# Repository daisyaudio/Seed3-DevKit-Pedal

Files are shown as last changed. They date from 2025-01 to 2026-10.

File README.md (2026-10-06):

# Seed3 Pedal Dev Kit

Seed3 Pedal Dev Kit

## An Effects Pedal Platform for the Daisy Seed3

The Seed3 Pedal Dev Kit provides everything you need to design and prototype your next Daisy-based effects pedal on a single, purpose-built board. Create powerful DSP effects — massive reverbs, delay networks, complex loopers, spectral processors, and granular engines the likes of which have yet to grace the pedal world.

With industry-standard components and circuitry onboard, moving a Daisy design into production has never been easier. On top of stereo I/O and a host of electromechanical controls, the Dev Kit includes DIN MIDI I/O, a TRS expression input, a microSD socket, and a USB-C port. Take your DSP pedals to the next level with Daisy.

---

## Contents

- [Features](#features)
- [Specifications](#specifications)
- [Getting Started](#getting-started)
- [Making Your Own Project](#making-your-own-project)
- [Hardware Reference](#hardware-reference)
- [Resources & Support](#resources--support)
- [Open-Source Hardware](#open-source-hardware)
- [License](#license)

---

## Features

| Category | Details |
| --- | --- |
| **Audio** | Stereo audio input and output |
| **MIDI** | DIN MIDI In, Out, and Thru |
| **Expression** | TRS expression pedal input |
| **USB** | USB-C port connected to the Seed3's external USB peripheral, for USB features in your firmware |
| **Storage** | microSD slot for firmware updates, samples, presets, configuration, and more |
| **Potentiometers** | 6 × 10kΩ linear (B-taper) |
| **Footswitches** | 2 × footswitches |
| **Buttons** | 2 × tactile switches |
| **Toggle Switches** | 3 × toggle switches (1 × ON-OFF-ON, 2 × ON-ON) |
| **LEDs** | 1 × RGB LED, 1 × red LED |
| **Power** | 9V DC barrel jack, center negative (standard pedal supply) |

## Specifications

| Parameter | Value |
| --- | --- |
| Processor module | Daisy Seed3 |
| Supply voltage | 9V DC, center negative |
| Current draw | Firmware dependent |
| Reverse polarity protection | Yes |
| Audio codec / sample rate | TAC5242 / up to 32-bit, 192kHz |
| Input impedance | 1MΩ |
| Output impedance | 100Ω |
| Board dimensions | 197mm × 100mm |
| Expression input | TRS |
| MIDI connectors | 3 × 5-pin DIN (In, Out, Thru) |

> [!WARNING]
> Use a **center-negative** 9V DC supply.

## Getting Started

### 1. Install the toolchain

Follow the Daisy [C++ Getting Started guide](https://docs.daisy.audio/tutorials/cpp-dev-env/). It installs the toolchain and clones [DaisyExamples](https://github.com/daisyaudio/DaisyExamples), which includes [libDaisy](https://github.com/daisyaudio/libDaisy) (hardware library) and [DaisySP](https://github.com/daisyaudio/DaisySP) (DSP library).

### 2. Update libDaisy
 
The Pedal Dev Kit template and board support are newer than the copy of libDaisy included with DaisyExamples. From your `DaisyExamples` folder, update libDaisy to its latest version, fetch its own dependencies, and rebuild it:
 
```bash
git submodule update --remote libDaisy
git -C libDaisy submodule update --init --recursive
make -C libDaisy
```
 
The first line moves libDaisy to its latest version. The second fetches libDaisy's own dependencies, such as the STM32 drivers it needs to compile. The last line rebuilds libDaisy, which is required after any update.
 
> [!CAUTION]
> Running `git submodule update --init --recursive` or `git pull --recurse-submodules` from the `DaisyExamples` folder afterwards resets libDaisy to the older version DaisyExamples was built with. If that happens, run the three commands above again.

### 3. Build the template

The starting project for this kit is [`examples/devkits/Pedal-DevKit-Template`](https://github.com/daisyaudio/libDaisy/tree/master/examples/devkits/Pedal-DevKit-Template). From the `libDaisy` folder:

```bash
cd examples/devkits/Pedal-DevKit-Template
make
```

This creates `Pedal-DevKit-Template.bin` in the template's `build/` folder.

### 4. Flash the Seed3

> [!IMPORTANT]
> Program the Seed3 through the **USB-C port on the Seed3 module itself**, not the USB-C port on the Dev Kit board.

1. Connect a USB-C cable from your computer to the Seed3's USB-C port.
2. Hold **BOOT**, press and release **RESET**, then release **BOOT**.
3. From the template folder, run:

   ```bash
   make program-dfu
   ```

   Or, in the [Daisy Web Programmer](https://flash.daisy.audio/), upload the `Pedal-DevKit-Template.bin` file from the `build/` folder.

### 5. Power up and try it out

Connect a 9V center-negative supply to the barrel jack (J8) and plug in your instrument and amp. You can leave the Seed3's USB cable connected so you can watch the serial output.

> [!TIP]
> If you are experiencing USB noise from keeping the Seed3 connected to the computer, disconnect during testing.

The template:

- Passes audio from the inputs straight to the outputs.
- Blinks the red LED (LED1) and cycles the colors of the RGB LED (LED2).
- Echoes MIDI notes received on MIDI In to MIDI Out.
- Prints the state of every control over USB serial on the Seed3's USB-C port. Open any serial monitor to see it.

## Making Your Own Project

Edits only take effect on the pedal after you rebuild and reflash, so start your own project from a copy of the template.

1. Copy the `Pedal-DevKit-Template` folder into your `DaisyExamples` folder and rename it, for example `DaisyExamples/MyPedal`.
2. In the copied `Makefile`:
   - Set `TARGET` to your project name, for example `TARGET = MyPedal`.
   - Change `LIBDAISY_DIR` to point to libDaisy from the new location: `LIBDAISY_DIR = ../libDaisy`.
   - To use DaisySP, uncomment the DaisySP line and set `DAISYSP_DIR = ../DaisySP`.
3. Write your effect in `src/main.cpp`. Audio is processed in `AudioCallback()`: inputs are `in[0][i]` (left) and `in[1][i]` (right), and outputs are `out[0][i]` and `out[1][i]` (see [Audio](#audio)).
4. Rebuild and flash after every change:

   ```bash
   make
   make program-dfu
   ```

   Put the Seed3 into BOOT mode (step 4 above) before each `make program-dfu`.

> [!TIP]
> The template builds with debugging enabled (`DEBUG = 1`, `OPT = -Og`). For release builds, set `DEBUG = 0` and `OPT = -O3` in the Makefile. If your program grows too large for the Seed3's internal flash, see the [Daisy Bootloader guide](https://docs.daisy.audio/tutorials/_a7_Getting-Started-Daisy-Bootloader/).

## Hardware Reference

The **Ref** column lists each part's reference designator, as printed on the board's silkscreen.

### Pinout

Seed3 Pedal Dev Kit pinout

A printable [Pinout PDF](https://daisy.nyc3.cdn.digitaloceanspaces.com/products/seed-3-pedal/Seed3-Pedal-Dev-Kit-Pinout.pdf) is also available.

### Audio

| Jack | Ref | Silkscreen | Signal | Audio Callback |
| --- | --- | --- | --- | --- |
| Input Left | J2 | IN LEFT | `AUDIO_IN_L` | `in[0][i]` |
| Input Right | J4 | IN RIGHT | `AUDIO_IN_R` | `in[1][i]` |
| Output Left | J3 | OUT LEFT | `AUDIO_OUT_L` | `out[0][i]` |
| Output Right | J5 | OUT RIGHT | `AUDIO_OUT_R` | `out[1][i]` |

### Controls

| Control | Ref | Signal | Seed3 Pin | Notes |
| --- | --- | --- | --- | --- |
| Potentiometer 1 | VR1 | `POT_1` | D15 | 10kΩ B-taper |
| Potentiometer 2 | VR2 | `POT_2` | D16 | 10kΩ B-taper |
| Potentiometer 3 | VR3 | `POT_3` | D17 | 10kΩ B-taper |
| Potentiometer 4 | VR4 | `POT_4` | D18 | 10kΩ B-taper |
| Potentiometer 5 | VR5 | `POT_5` | D19 | 10kΩ B-taper |
| Potentiometer 6 | VR6 | `POT_6` | D20 | 10kΩ B-taper |
| Expression input | J6 | `ADC_EXPRESSION` | D21 | TRS |
| Footswitch 1 | FSW_1 | `GPIO_FSW_1` | D10 | |
| Footswitch 2 | FSW_2 | `GPIO_FSW_2` | D23 | |
| Tactile switch 1 | SW3 | `TAC_SW1` | D0 | |
| Tactile switch 2 | SW4 | `TAC_SW2` | D28 | |
| Toggle switch 1 | SW1 | `TOG_2_A` / `TOG_2_B` | D8 / D7 | ON-OFF-ON (3-position, two pins) |
| Toggle switch 2 | SW2 | `TOG_1` | D9 | ON-ON |
| Toggle switch 3 | SW6 | `TOG_3` | D22 | ON-ON |

### LEDs

| LED | Ref | Signal | Seed3 Pin |
| --- | --- | --- | --- |
| Red LED | LED1 | `LED_MONO_1` | D24 |
| RGB LED — Red | LED2 | `LED_R` | D25 |
| RGB LED — Green | LED2 | `LED_G` | D27 |
| RGB LED — Blue | LED2 | `LED_B` | D26 |

### MIDI

| Jack | Ref | Signal | Seed3 Pin | Direction |
| --- | --- | --- | --- | --- |
| MIDI Out | J11 | `MIDI_TX` | D13 | Out |
| MIDI In | J10 | `MIDI_RX` | D14 | In |
| MIDI Thru | J1 | `MIDI_RX` | D14 | Mirrors MIDI In |

### microSD (SDMMC, 4-bit)

| Signal | Seed3 Pin |
| --- | --- |
| `SDMMC_CK` | D6 |
| `SDMMC_CMD` | D5 |
| `SDMMC_D0` | D4 |
| `SDMMC_D1` | D3 |
| `SDMMC_D2` | D2 |
| `SDMMC_D3` | D1 |

### USB-C

The Dev Kit's USB-C port connects to the Seed3's external USB peripheral. It is separate from the USB-C port on the Seed3 module, which is used for programming and for the template's serial output.

| Signal | Seed3 Pin |
| --- | --- |
| `USB_OTG_HS_N` | D29 |
| `USB_OTG_HS_P` | D30 |

### Power

| Connector | Ref | Notes |
| --- | --- | --- |
| DC barrel jack | J8 | 9V DC, center negative |

## Resources & Support

- **Product Page:** [Seed3 Pedal Dev Kit](https://daisy.audio/products/seed3-development-kit-pedal)
- **Documentation:** [docs.daisy.audio](https://docs.daisy.audio/product/Seed3-Pedal-Dev-Kit/)
- **Community Forum:** [community.daisy.audio](https://community.daisy.audio)
- **Discord:** [Daisy Discord](https://discord.gg/ByHBnMtQTR)
- **Issues:** Report bugs or hardware errata via this repository's [Issues](../../issues) tab.

### Design Files

- [Schematic (PDF)](https://daisy.nyc3.cdn.digitaloceanspaces.com/products/seed-3-pedal/ES-Seed3-DevKit-Pedal-Rev3.pdf)
- [Bill of Materials (CSV)](https://daisy.nyc3.cdn.digitaloceanspaces.com/products/seed-3-pedal/Seed3-DevKit-Pedal_Rev4-bom.csv)
- [Pinout (PDF)](https://daisy.nyc3.cdn.digitaloceanspaces.com/products/seed-3-pedal/Seed3-Pedal-Dev-Kit-Pinout.pdf)
- [KiCad Design Files](https://github.com/daisyaudio/ES-Seed3-DevKit-Pedal/releases/latest)

---

## Open-Source Hardware

Open Source Hardware logo

The Pedal Dev Kit is open-source hardware, built to the [Open Source Hardware Definition](https://www.oshwa.org/definition/) published by the Open Source Hardware Association (OSHWA). The schematics, PCB layouts, bill of materials, and KiCad source files are published so that you can study, modify, manufacture, and sell your own designs based on them.

## License

Copyright © 2026 Qu-Bit Electronix, Inc. (dba Daisy)

The hardware design files in this repository are licensed under the **CERN Open Hardware Licence Version 2 – Permissive** ([CERN-OHL-P-2.0](https://ohwr.org/cern_ohl_p_v2.pdf)).

Subject to the terms of that licence, you may:

- Use, study, copy, modify, and distribute these designs and any products made from them.
- Incorporate these designs, in whole or in part, into closed-source and commercial products.

These designs are provided "as is", without warranty of any kind, express or implied. See [LICENSE](LICENSE.txt) for the full licence text, including the disclaimer of warranty and limitation of liability.

Firmware and software, including [libDaisy](https://github.com/daisyaudio/libDaisy) and [DaisySP](https://github.com/daisyaudio/DaisySP), are licensed separately under the terms included in their respective repositories.

SPDX-License-Identifier: CERN-OHL-P-2.0

### Trademarks

DAISY® is a trademark of Qu-Bit Electronix, Inc., registered in the United States. CERN-OHL-P-2.0 grants a license to the copyright and related rights in these designs. It does not grant any right or license to use the DAISY name, logos, product names, or other trademarks of Qu-Bit Electronix, Inc.

Products, derivative designs, and related materials made from these designs may not:

- Use the DAISY name or logo, or any confusingly similar name or mark, in a product name, model number, brand, domain name, or marketing material.
- Reproduce the DAISY name or logo on a PCB silkscreen, front panel, enclosure, packaging, or documentation, except where needed to keep the required licence notices.
- State or imply that the product is made, endorsed, sponsored, certified, or supported by Qu-Bit Electronix, Inc.

You may make truthful, factual statements about compatibility or origin, such as "based on the Seed3 Pedal Dev Kit design" or "compatible with the Daisy Seed3", provided the statement does not suggest affiliation or endorsement. If you redistribute or sell products derived from these designs, remove the DAISY name and logo from the silkscreen and other artwork before manufacture.

For trademark licensing or permission requests, contact Qu-Bit Electronix, Inc. through [daisy.audio/pages/support](https://daisy.audio/pages/support).

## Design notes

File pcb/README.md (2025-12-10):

# PCB changelog

## Rev3

- Updated rev text (on bottom side) to Rev3
- Marked R10, and R19 as populate, and R9 as DNP to swap the mid-rail voltage to ~+4V5
- Updated R43 (RED LED Resistor) to 1K (previously 2K)
- Updated C8 and C28 to 100pF (previously 1nF) to fix tone-suck/low-pass filtering of guitars, etc.
- Updated R75 and R12 to 33K (previously 24K) to improve pass-through level in the audio I/O circuits
- Renamed toggle/button switches so that they're designators match the order of the layout.
- Updated copyright to "(C) Daisy 2025"
- Added silkscreen indications for each Daisy pin to the corresponding electro-mechanical element.
- Updated footprints to not be our PIP footprints
- Replaced QR code with new code to proper redirect page
- Added SD Card detect via unused pin on seed.
- Updated sch symbol for TRS jacks to a kicad native footprint
- Slight layout changes to accommodate larger courtyard on 1/4" Jack footprint

### Footprints swapped

| Type | New footprint |
| ---- | --- |
| 1/4" jack | Connector_audio:Jack_6.35mm_Neutrik_NMJ6HCD2_Horizontal |
| Pots | parts-for-kicad:9MM_SNAP_-IN_POT_SILK |
| Toggle (on-on) | Electrosmith-Interface:TOGGLE_ON-ON |
| Toggle (on-off-on) | Electrosmith-Interface:TOGGLE_ON_OFF_ON |

## Rev2

Lots of little changes, and removed relays, etc.

## Rev1

Initial Rev

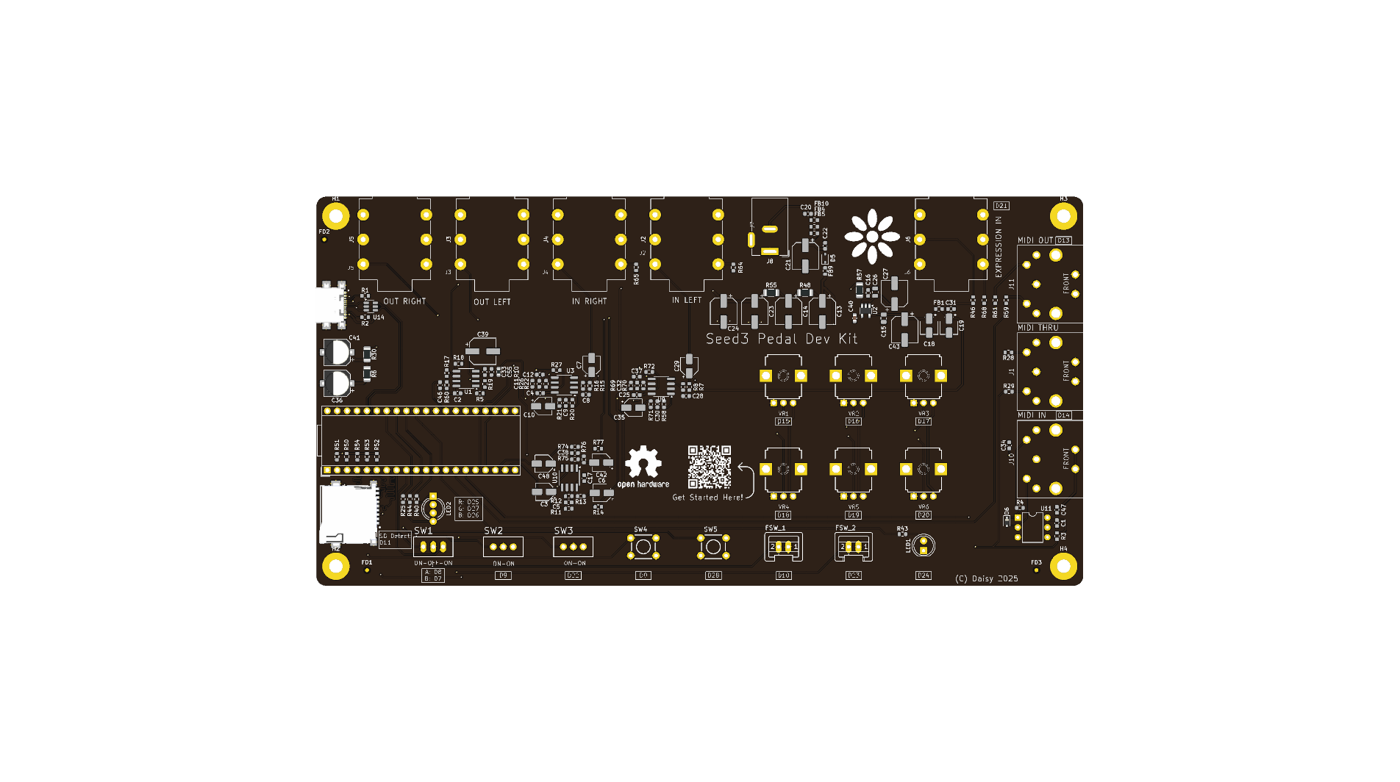
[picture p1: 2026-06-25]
pcb/ES-Seed3-DevKit-Pedal-Rev4/review/2026-06-18/board-render/render_top.png

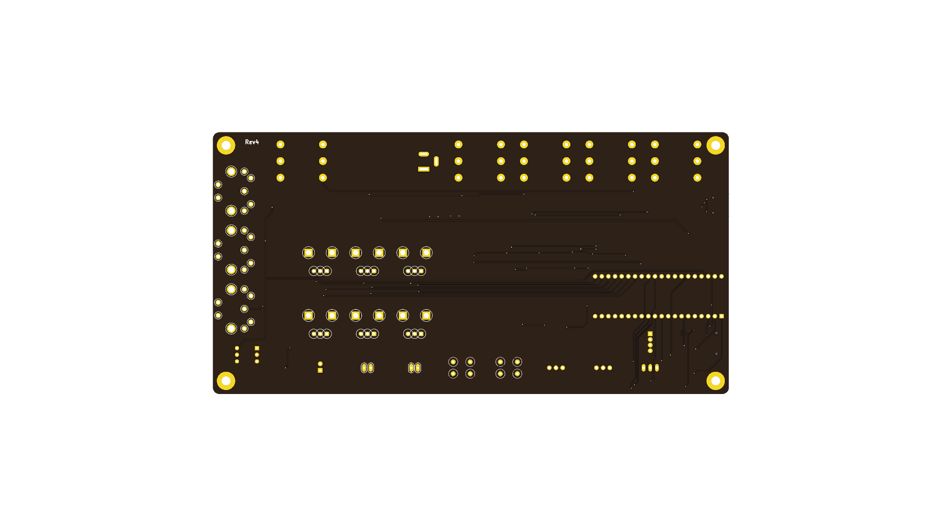
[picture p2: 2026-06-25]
pcb/ES-Seed3-DevKit-Pedal-Rev4/review/2026-06-18/board-render/render_bottom.png

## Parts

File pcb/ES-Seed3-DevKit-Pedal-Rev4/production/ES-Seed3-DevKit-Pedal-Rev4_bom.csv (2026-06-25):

Value | Reference | Footprint | Qty | AVL_Part_Number
10uF | C3,C6,C7,C10,C29,C35,C42,C48 | Capacitor_SMD:CP_Elec_4x5.8 | 8 | 10uF
M12 SPST Footswitch Assembly | FSW_1,FSW_2 | parts-for-kicad:S02P | 2 | M12 SPST Footswitch Assembly
1NF | C9,C30 | Capacitor_SMD:C_0603_1608Metric | 2 | 1NF C0603
1UF | C55 | Capacitor_SMD:C_0603_1608Metric | 1 | 1UF C0603
3R3 | R6,R30,R48,R55,R57 | Resistor_SMD:R_1206_3216Metric | 5 | 3R3
10R | R28,R29,R59,R61 | Resistor_SMD:R_0603_1608Metric | 4 | 10R R0603
10NF | C40,C46 | Capacitor_SMD:C_0603_1608Metric | 2 | 10NF C0603
10UF | C15,C26 | Capacitor_SMD:C_0805_2012Metric | 2 | 10UF C0805
10UF | C18,C19 | Capacitor_SMD:CP_Elec_4x5.8 | 2 | 10UF
33NF | C12,C37 | Capacitor_SMD:C_0603_1608Metric | 2 | 33NF C0603
100NF | C1,C2,C4,C16,C17,C20,C22,C25,C31,C33,C34,C47 | Capacitor_SMD:C_0603_1608Metric | 12 | 100NF C0603
100R | R8,R13,R16,R27,R46,R72,R76 | Resistor_SMD:R_0603_1608Metric | 7 | 100R R0603
100UF | C13,C14,C21,C23,C24,C27,C36,C39,C41,C43 | Capacitor_SMD:CP_Elec_6.3x7.7 | 10 | 100UF
220R | R4 | Resistor_SMD:R_0603_1608Metric | 1 | 220R R0603
270R | R3 | Resistor_SMD:R_0603_1608Metric | 1 | 270R R0603
1K | R43 | Resistor_SMD:R_0603_1608Metric | 1 | 1K R0603
2K | R25,R40,R44 | Resistor_SMD:R_0603_1608Metric | 3 | 2K R0603
3K3 | R20,R58 | Resistor_SMD:R_0603_1608Metric | 2 | 3K3 R0603
4K7 | R21,R71 | Resistor_SMD:R_0603_1608Metric | 2 | 4K7 R0603
5K1 | R1,R2 | Resistor_SMD:R_0603_1608Metric | 2 | 5K1 R0603
10K | R5,R10,R14,R17,R19,R22,R26,R64,R65,R68,R69,R70,R77 | Resistor_SMD:R_0603_1608Metric | 13 | 10K R0603
15K | R11,R74 | Resistor_SMD:R_0603_1608Metric | 2 | 15K R0603
20K | R60 | Resistor_SMD:R_0603_1608Metric | 1 | 20K R0603
33K | R12,R75 | Resistor_SMD:R_0603_1608Metric | 2 | 33K R0603
47K | R50,R51,R52,R53,R54 | Resistor_SMD:R_0603_1608Metric | 5 | 47K R0603
1M | R7,R15,R18 | Resistor_SMD:R_0603_1608Metric | 3 | 1M R0603
100PF | C5,C8,C28,C38 | Capacitor_SMD:C_0603_1608Metric | 4 | 100PF C0603
270PF | C11,C32 | Capacitor_SMD:C_0603_1608Metric | 2 | 270PF C0603
Barrel_Jack_Switch | J8 | Connector_BarrelJack:BarrelJack_Wuerth_6941xx301002 | 1 | Barrel_Jack_Switch
DIN_MIDI_5P | J1,J10,J11 | parts-for-kicad:57PC5F | 3 | DIN_MIDI_5P
Electrosmith_Daisy_Seed_Rev4 | A1 | Module:Electrosmith_Daisy_Seed | 1 | Electrosmith_Daisy_Seed_Rev4
FERRITE_BEAD_0603 | FB1,FB4,FB5,FB9,FB10 | Resistor_SMD:R_0603_1608Metric | 5 | FERRITE_BEAD_0603 R0603
H11L1 | U11 | Package_DIP:DIP-6_W7.62mm | 1 | H11L1
JACK_TRS_SWITCHING | J2,J3,J4,J5,J6 | Connector_Audio:Jack_6.35mm_Neutrik_NMJ6HCD2_Horizontal | 5 | JACK_TRS_SWITCHING
LED | LED1 | LED_THT:LED_D5.0mm | 1 | LED
LED_RKBG | LED2 | LED_THT:LED_D5.0mm-4_RGB_Wide_Pins | 1 | LED_RKBG
LP2985-5.0 | U2 | Package_TO_SOT_SMD:SOT-23-5 | 1 | LP2985-5.0
MCP6002-xSN | U1 | Package_SO:SOIC-8_3.9x4.9mm_P1.27mm | 1 | MCP6002-xSN
MICRO_SD_CARD | U7 | TF-01A:TF-01A | 1 | MICRO_SD_CARD
NSR1020MW2T3G | D5,D6 | Diode_SMD:D_SOD-323 | 2 | NSR1020MW2T3G
OPA1652 | U3,U9,U10 | Package_SO:SOIC-8_3.9x4.9mm_P1.27mm | 3 | OPA1652
P-10K-B-R | VR1,VR2,VR3,VR4,VR5,VR6 | parts-for-kicad:9MM_SNAP-IN_POT_SILK | 6 | P-10K-B-R
PTH Mini Button | SW4,SW5 | parts-for-kicad:TL1105SPF250Q_SILK | 2 | PTH Mini Button
TOGGLE_ON-ON_PIP3 | SW2,SW3 | parts-for-kicad:TOGGLE_ON_ON_2 | 2 | TOGGLE_ON-ON_PIP3
TOGGLE_ON_OFF_ON_PIP2 | SW1 | parts-for-kicad:TOGGLE_ON_OFF_ON | 1 | TOGGLE_ON_OFF_ON_PIP2
USB4110GFA | J7 | USB4110GFA:GCT_USB4110GFA | 1 | USB4110GFA
USBLC6-2SC6 | U14 | Package_TO_SOT_SMD:SOT-23-6 | 1 | USBLC6-2SC6

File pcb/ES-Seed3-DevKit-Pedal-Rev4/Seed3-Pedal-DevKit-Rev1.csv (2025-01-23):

Id | Designator | Footprint | Quantity | Designation | Supplier and ref
1 | R46,R8,R48,R13,R72,R27,R76,R16,R55 | R_0603_1608Metric | 9 | 100R
2 | FD3,FD1,FD2 | Fiducial_1mm_Mask2mm | 3 | FIDUCIAL
3 | C46 | C_0603_1608Metric | 1 | 10NF
4 | R61,R57,R62,R29,R28,R59,R63 | R_0603_1608Metric | 7 | 10R
5 | SW4,SW3 | TL3301SPF160QJ | 2 | SMT Mini Button
6 | C30,C9,C28,C8 | C_0603_1608Metric | 4 | 1NF
7 | R77,R26,R56,R22,R14,R69,R65,R5,R19,R17,R68,R70,R64 | R_0603_1608Metric | 13 | 10K
8 | Q1,Q5 | SOT-23 | 2 | 3904
9 | C5,C38 | C_0603_1608Metric | 2 | 100PF
10 | C31,C47,C33,C20,C2,C25,C34,C22,C4,C16,C17,C1 | C_0603_1608Metric | 12 | 100NF
11 | R50,R51,R52,R54,R53 | R_0603_1608Metric | 5 | 47K
12 | C27,C24,C43,C36,C14,C21,C39,C13,C41,C23 | CP_Elec_6.3x7.7 | 10 | 100UF
13 | U3,U10,U9 | SOIC-8_5.275x5.275mm_P1.27mm | 3 | OPA1652
14 | FB2,FB5,FB8,FB1,FB9,FB10,FB3,FB4,FB7 | R_0603_1608Metric | 9 | FERRITE_BEAD_0603
15 | R2,R1 | R_0603_1608Metric | 2 | 5K1
16 | H1,H2,H3,H4 | MountingHole_3.5mm_Pad | 4 | MOUNT-PAD-ROUND3.5
17 | LOGO1 | OSHW-LOGO-L_TEXT | 1 | OSHW-LOGO
18 | J5,J2,J6,J3,J4 | TRS_JACK_WQP-PJ609B | 5 | JACK_TRS_SWITCHING
19 | C12,C37 | C_0603_1608Metric | 2 | 33NF
20 | J11,J1,J10 | 57PC5F | 3 | DIN_MIDI_5P
21 | VR3,VR5,VR1,VR4,VR6,VR2 | 9MM_SNAP-IN_POT_SILK_PIP | 6 | P-10K-B-R-PIP
22 | R44,R9,R43,R10,R24,R23,R40,R25 | R_0603_1608Metric | 8 | 2K
23 | R60 | R_0603_1608Metric | 1 | 20K
24 | SW2,SW6 | TOGGLE_SILK_PIP3 | 2 | TOGGLE_ON-ON_PIP3
25 | U8 | SOT-223-3_TabPin2 | 1 | LD1117-5V
26 | R21,R71 | R_0603_1608Metric | 2 | 4K7
27 | R7,R15,R18 | R_0603_1608Metric | 3 | 1M
28 | C29,C48,C10,C42,C7,C35,C6,C3 | CP_Elec_4x5.8 | 8 | 10uF
29 | D6,D5 | D_SOD-323 | 2 | NSR1020MW2T3G
30 | LED1 | LED_D5.0mm | 1 | LED
31 | R11,R74 | R_0603_1608Metric | 2 | 15K
32 | A1 | Electrosmith_Daisy_Seed | 1 | Electrosmith_Daisy_Seed_Rev4
33 | C11,C32 | C_0603_1608Metric | 2 | 270PF
34 | U6,U5 | RELAY-SMD_G6K-2F-Y | 2 | G6K-2F-Y-TR DC3
35 | C26,C15 | C_0805_2012Metric | 2 | 10UF
36 | R75,R12 | R_0603_1608Metric | 2 | 24K
37 | R58,R20 | R_0603_1608Metric | 2 | 3K3
38 | D3,D4 | D_SOD-323 | 2 | 1N4148
39 | U11 | DIP-6_W7.62mm | 1 | H11L1
40 | FSW_1,FSW_2 | S02P | 2 | M12 SPST Footswitch Assembly
41 | U14 | SOT-23-6 | 1 | USBLC6-2SC6
42 | C55 | C_0603_1608Metric | 1 | 1UF
43 | SW1 | TOGGLE_SILK_PIP3 | 1 | TOGGLE_ON_OFF_ON_PIP2
44 | R3 | R_0603_1608Metric | 1 | 270R
45 | C18,C19 | CP_Elec_4x5.8 | 2 | 10UF
46 | LED2 | LED_D5.0mm-4_RGB_Wide_Pins | 1 | LED_RKBG
47 | U1 | SOIC-8_5.275x5.275mm_P1.27mm | 1 | MCP6002-xSN
48 | L2 | SDR0805 | 1 | SDR0805-102KL
49 | U7 | MEM2061-01-188-00-A_GCT | 1 | MICRO_SD_CARD
50 | J8 | BarrelJack_Wuerth_6941xx301002 | 1 | Barrel_Jack_Switch
51 | U4 | USB-C-SMD_G-SWITCH_GT-USB-7010ASV | 1 | GT-USB-7010ASV
52 | R4 | R_0603_1608Metric | 1 | 220R

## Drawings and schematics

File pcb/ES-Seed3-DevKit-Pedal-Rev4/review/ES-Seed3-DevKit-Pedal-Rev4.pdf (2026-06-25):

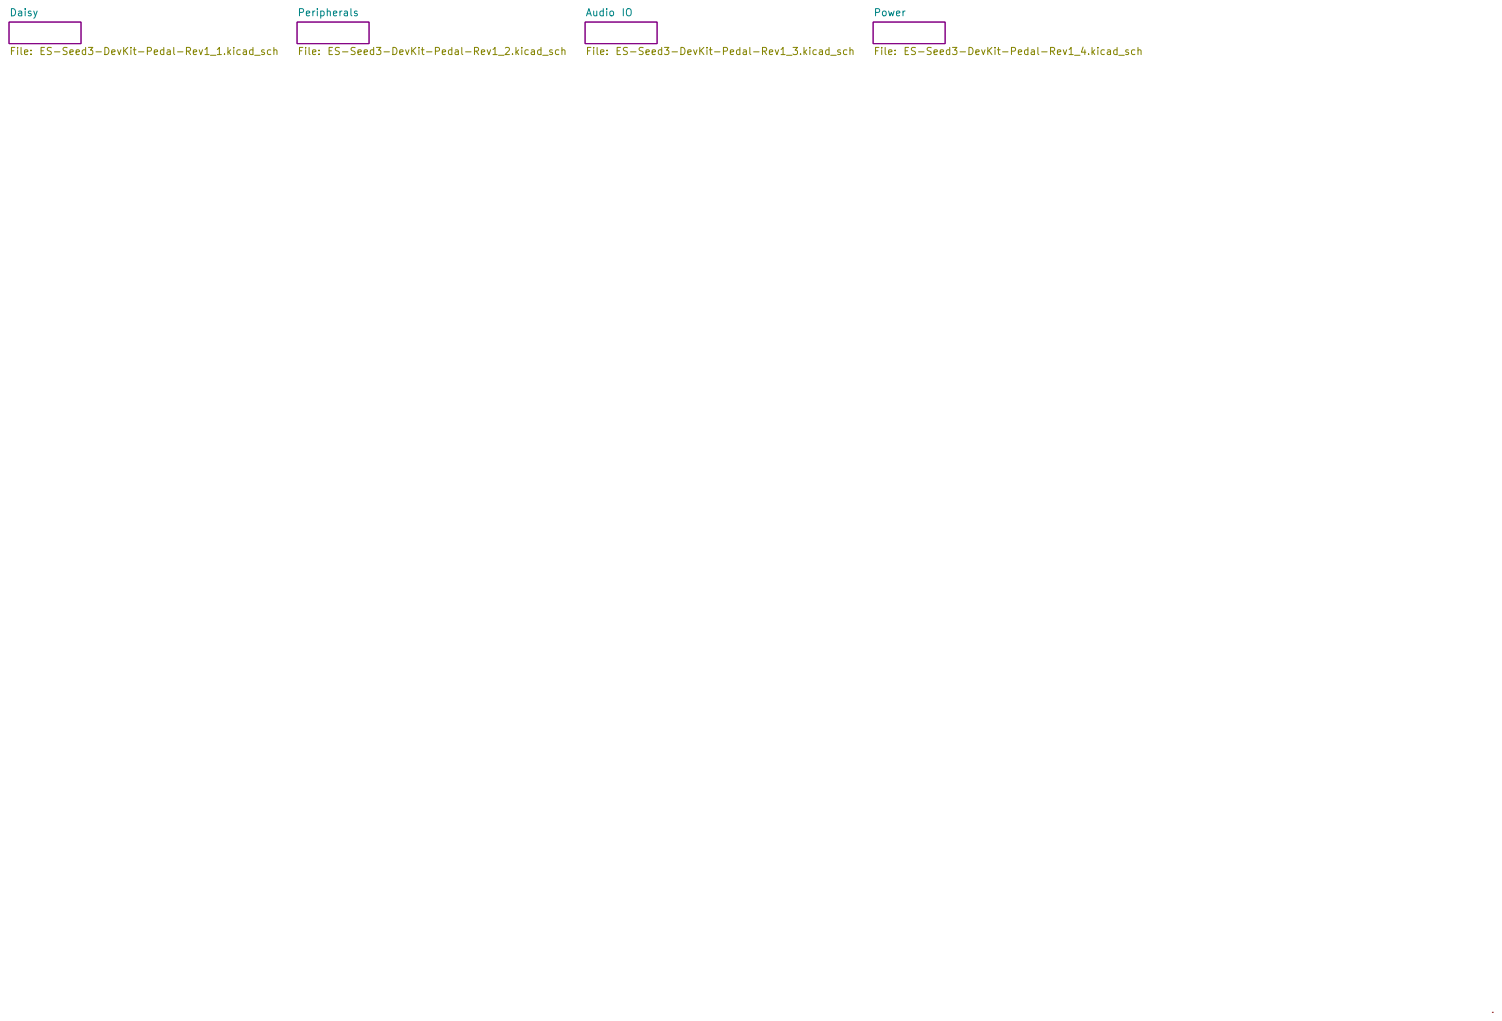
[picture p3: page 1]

File: ES-Seed3-DevKit-Pedal-Rev1_3.kicad_sch Daisy File: ES-Seed3-DevKit-Pedal-Rev1_1.kicad_sch

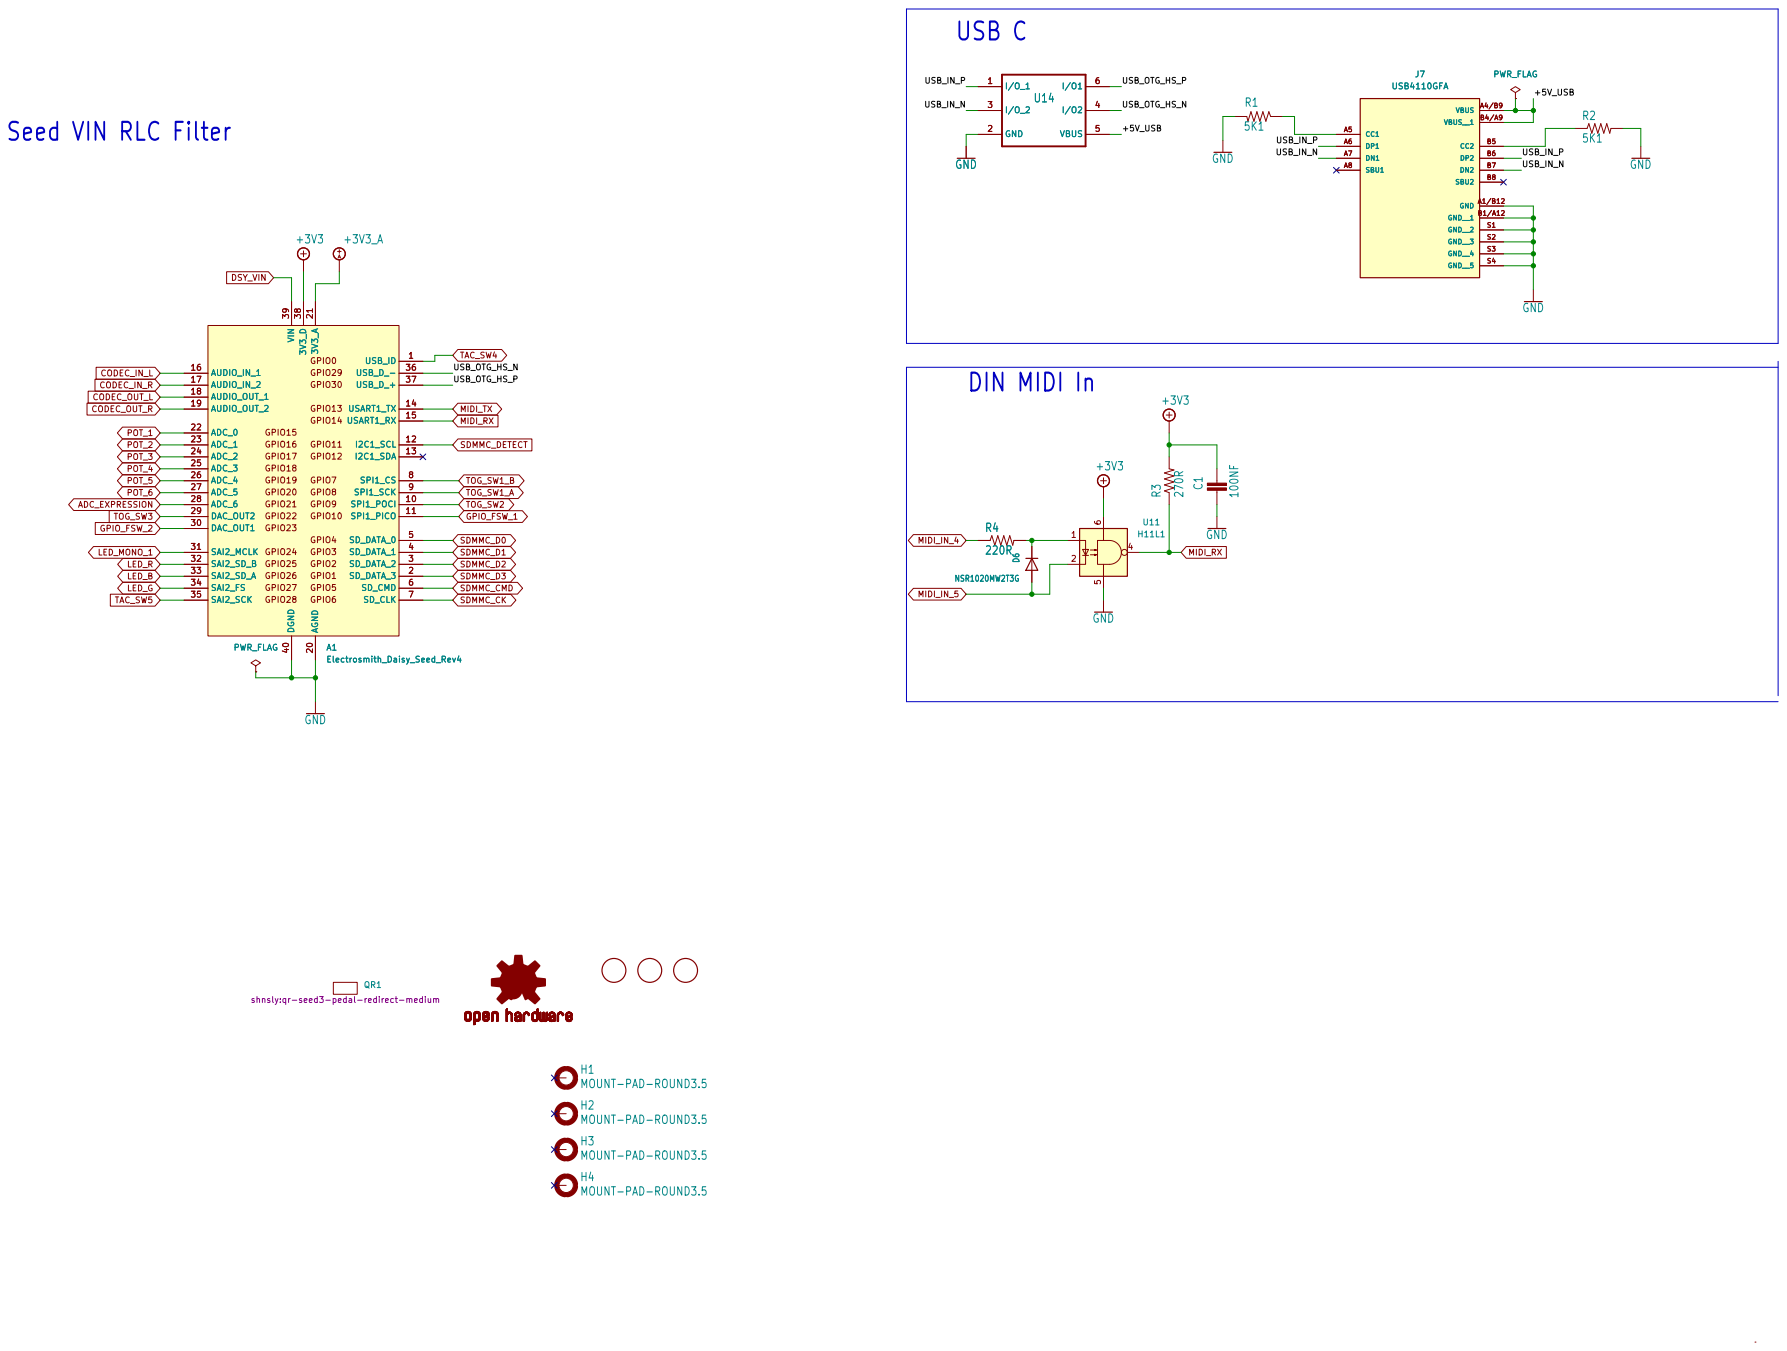
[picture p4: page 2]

shnsly:qr-seed3-pedal-redirect-medium

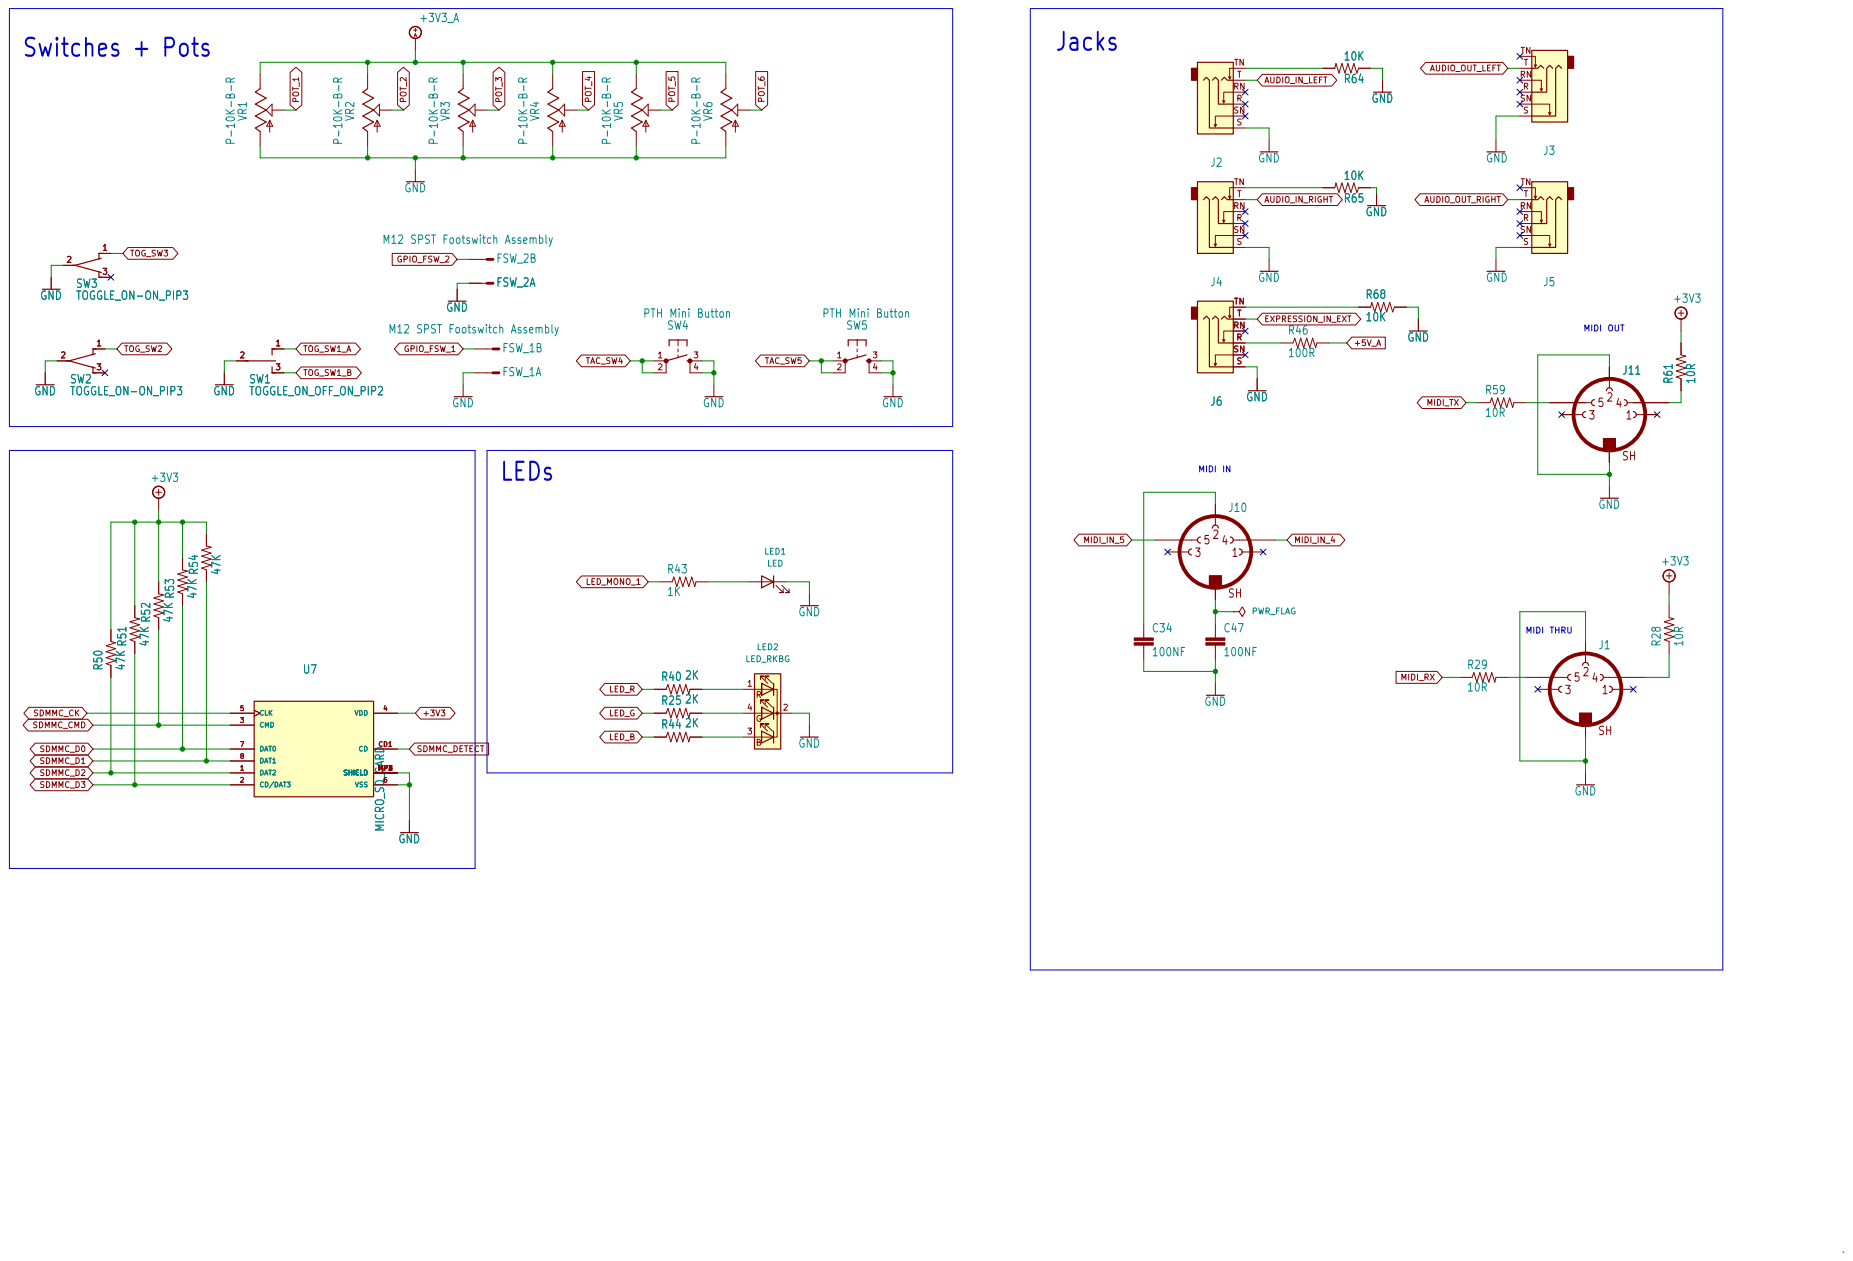
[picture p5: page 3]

MIDI THRU MIDI OUT SD Card

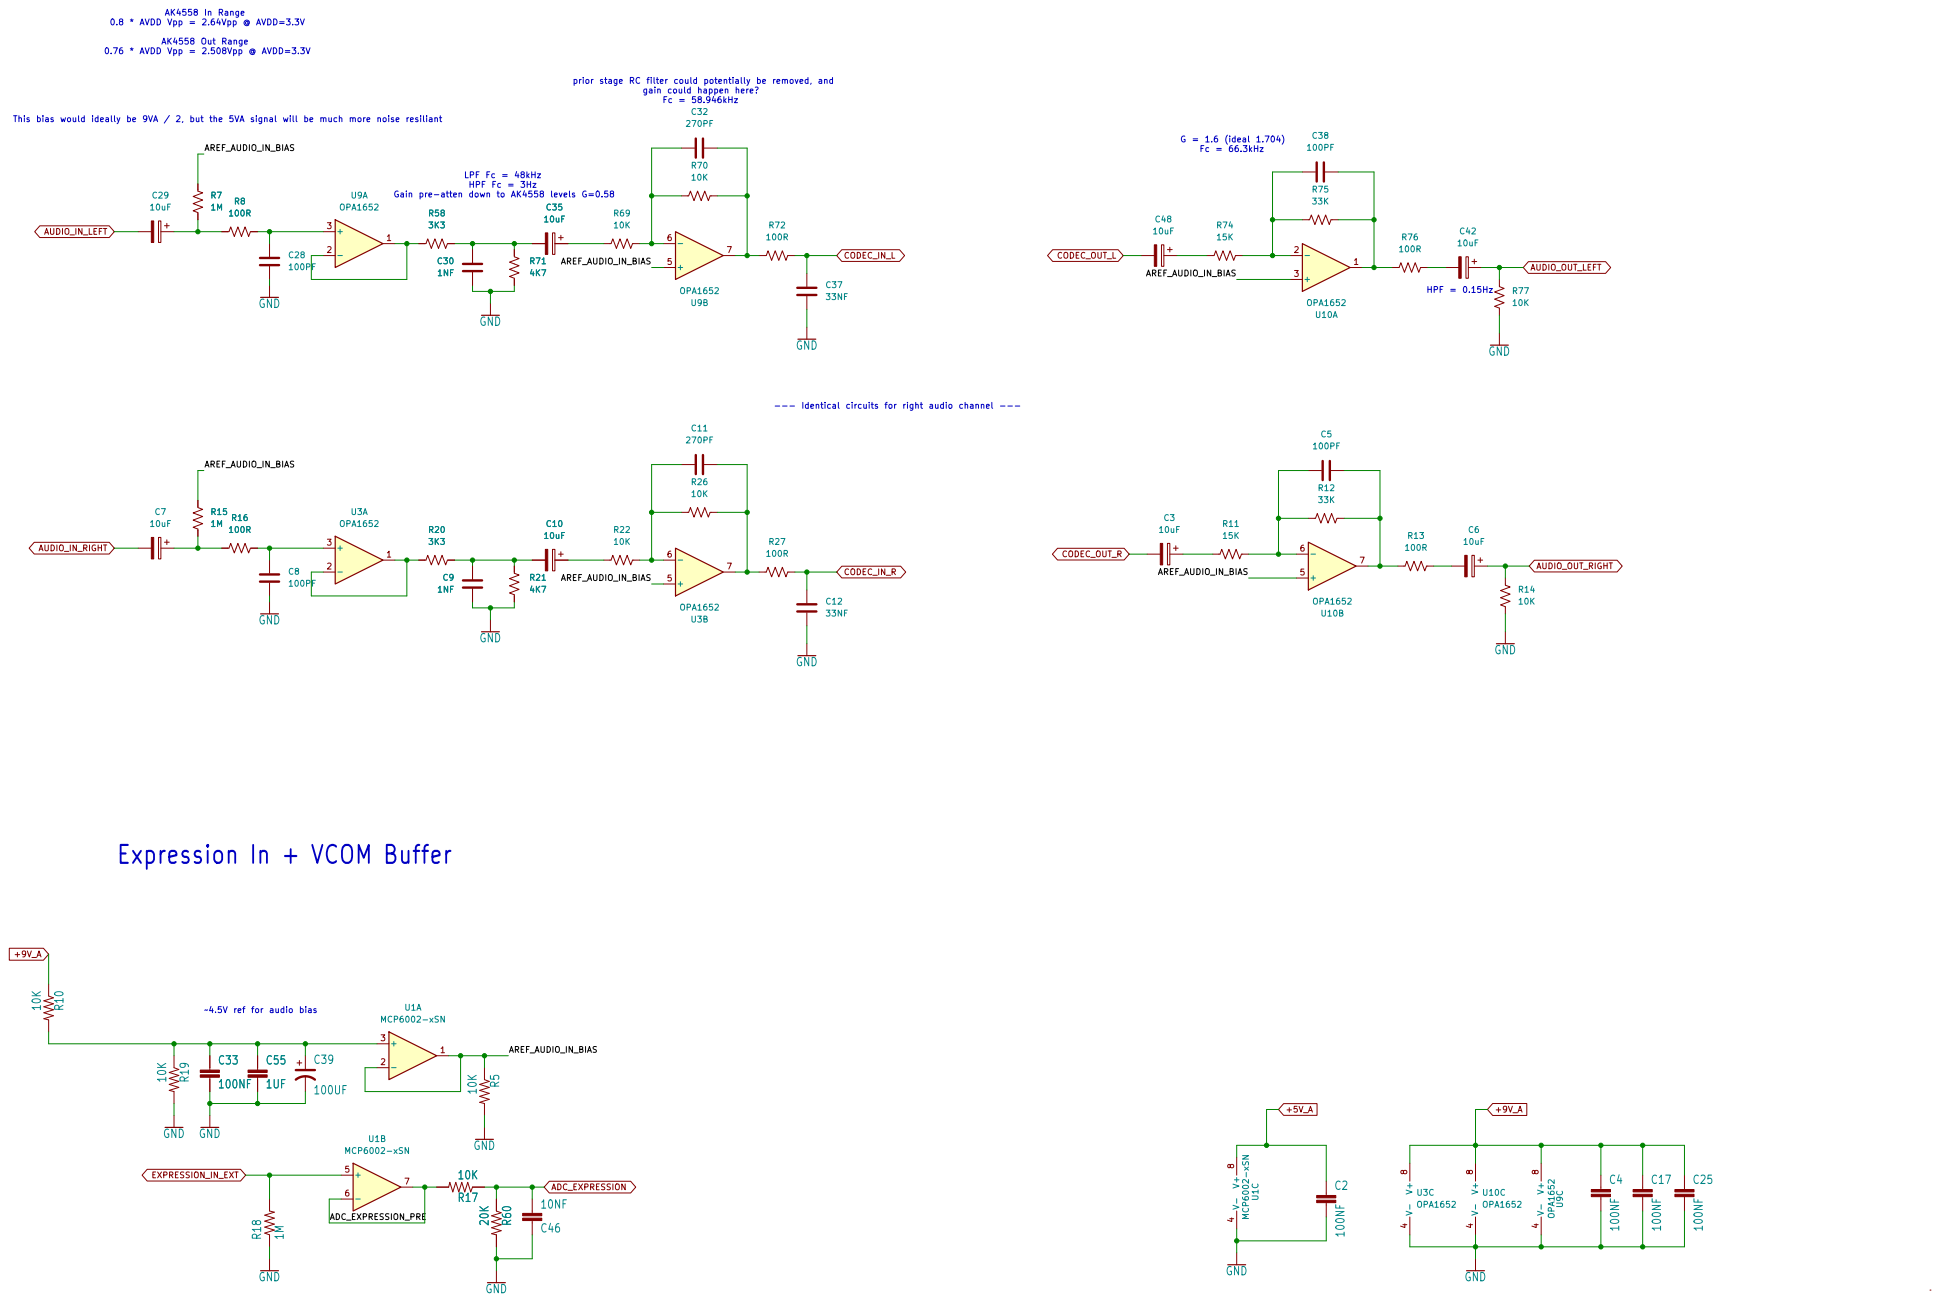
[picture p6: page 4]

This bias would ideally be 9VA / 2, but the 5VA signal will be much more noise resiliant AK4558 In Range 0.8 * AVDD Vpp = 2.64Vpp @ AVDD=3.3V
AREF_AUDIO_IN_BIAS Expression In + VCOM Buffer

AK4558 Out Range 0.76 * AVDD Vpp = 2.508Vpp @ AVDD=3.3V R8

HPF = 0.15Hz G = 1.6 (ideal 1.704) Fc = 66.3kHz prior stage RC filter could potentially be removed, and

gain could happen here?

LPF Fc = 48kHz HPF Fc = 3Hz Gain pre-atten down to AK4558 levels G=0.58

~4.5V ref for audio bias

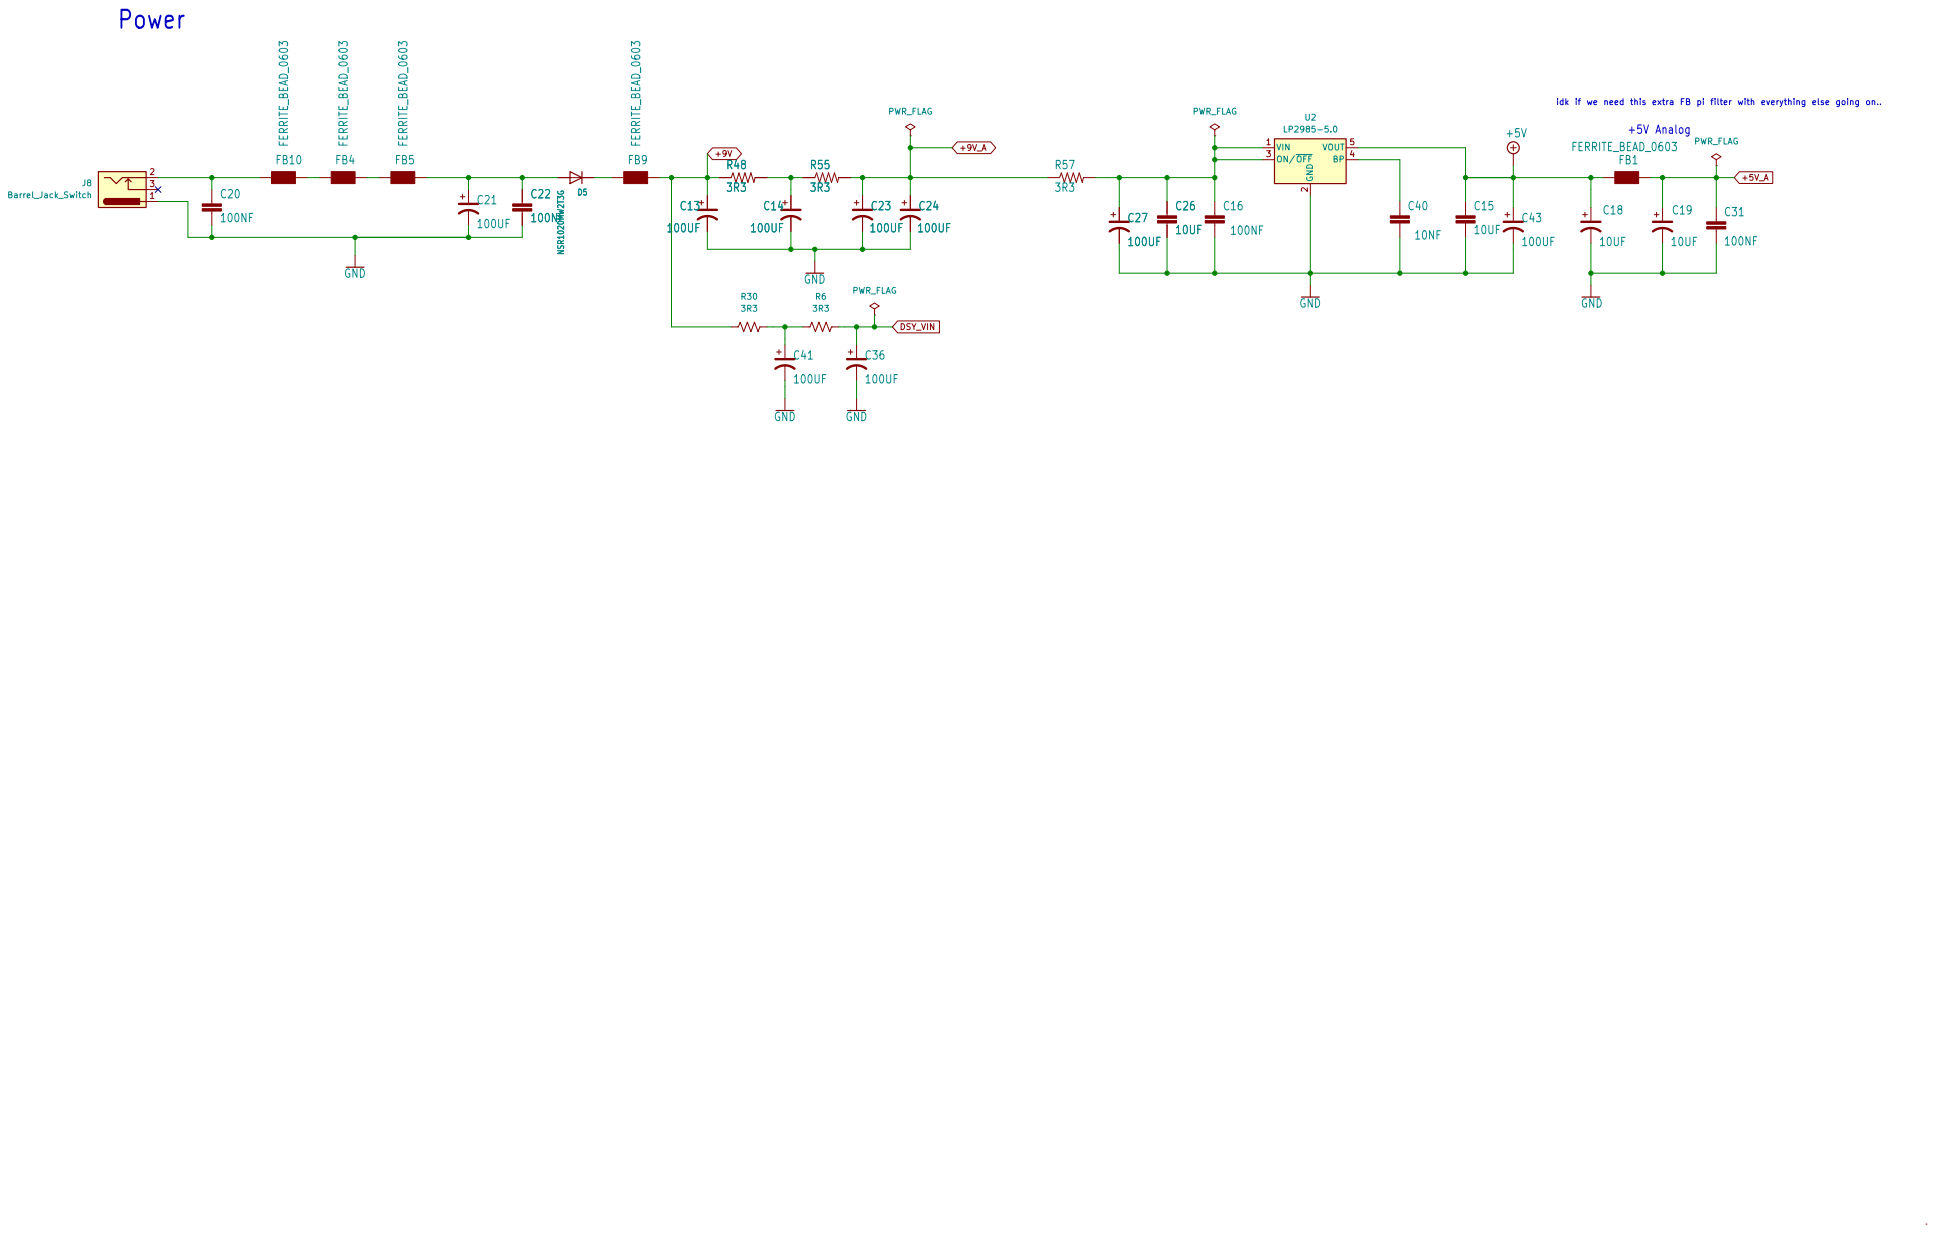
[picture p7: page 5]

idk if we need this extra FB pi filter with everything else going on.. D5 NSR1020MW2T3GC22

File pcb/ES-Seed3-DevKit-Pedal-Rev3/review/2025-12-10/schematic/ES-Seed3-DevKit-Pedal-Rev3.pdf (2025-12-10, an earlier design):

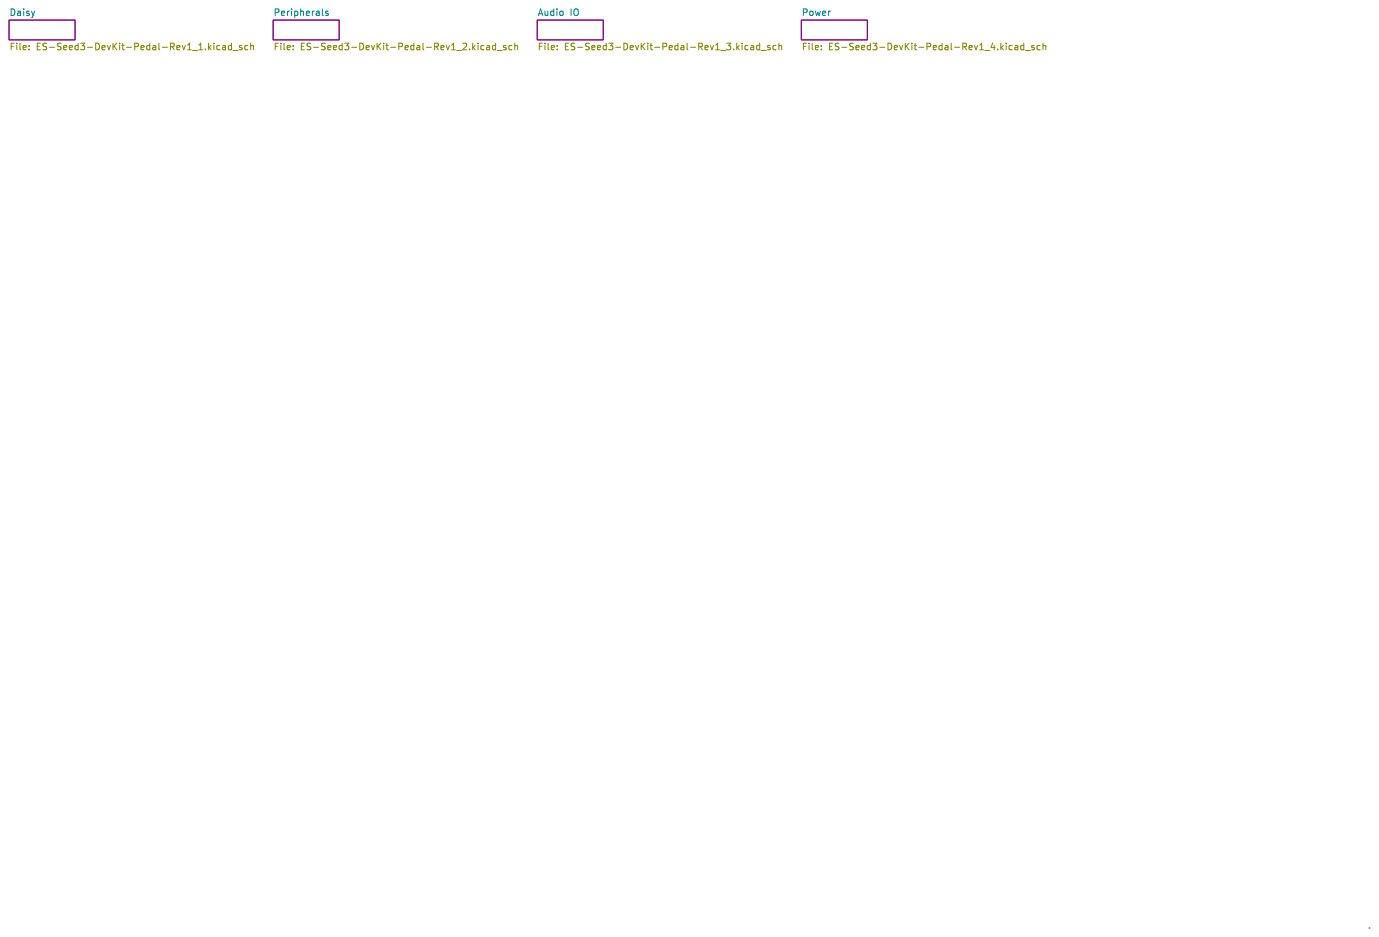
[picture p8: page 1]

File: ES-Seed3-DevKit-Pedal-Rev1_3.kicad_sch Daisy File: ES-Seed3-DevKit-Pedal-Rev1_1.kicad_sch

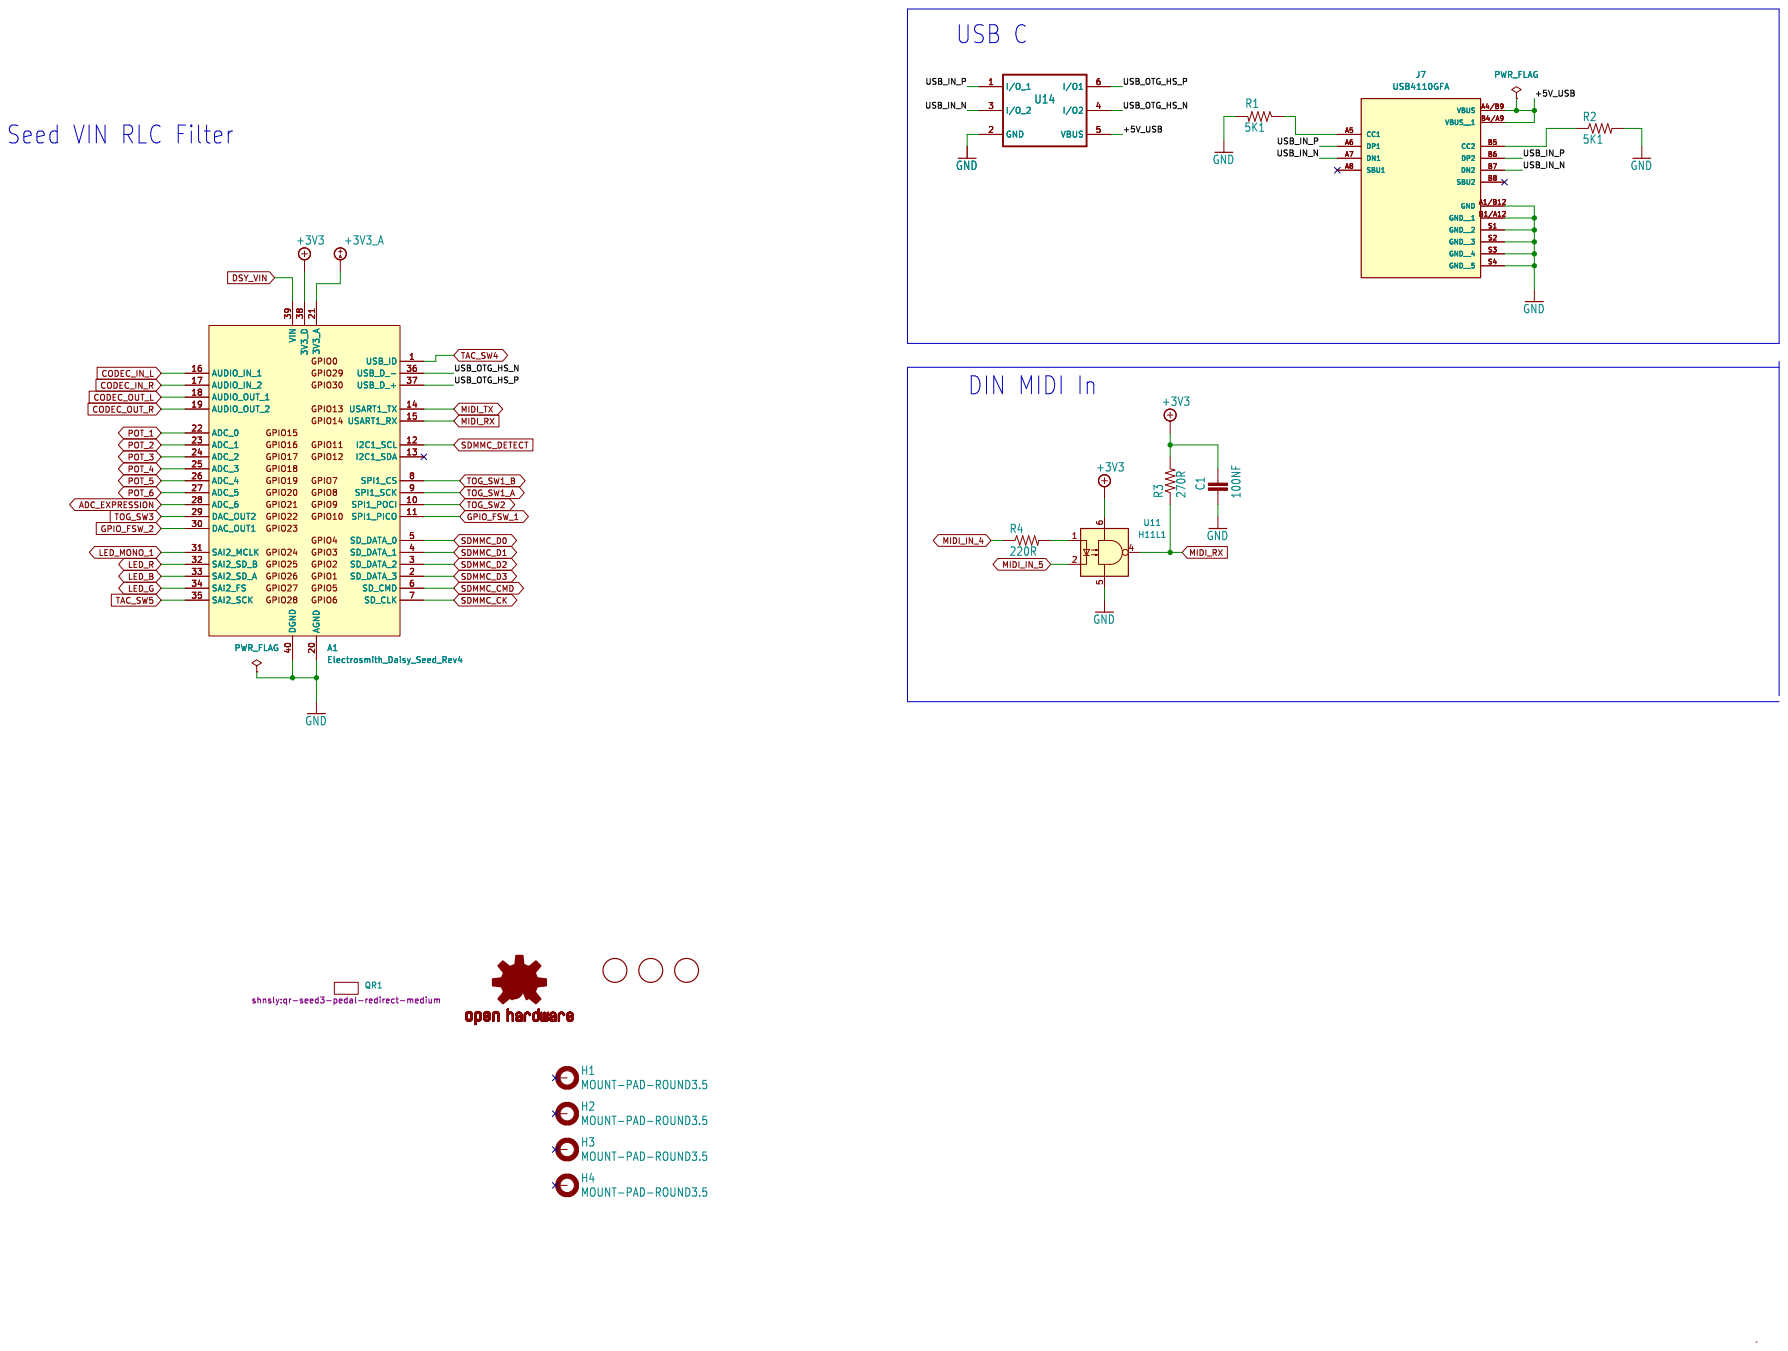
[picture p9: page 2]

Seed VIN RLC Filter

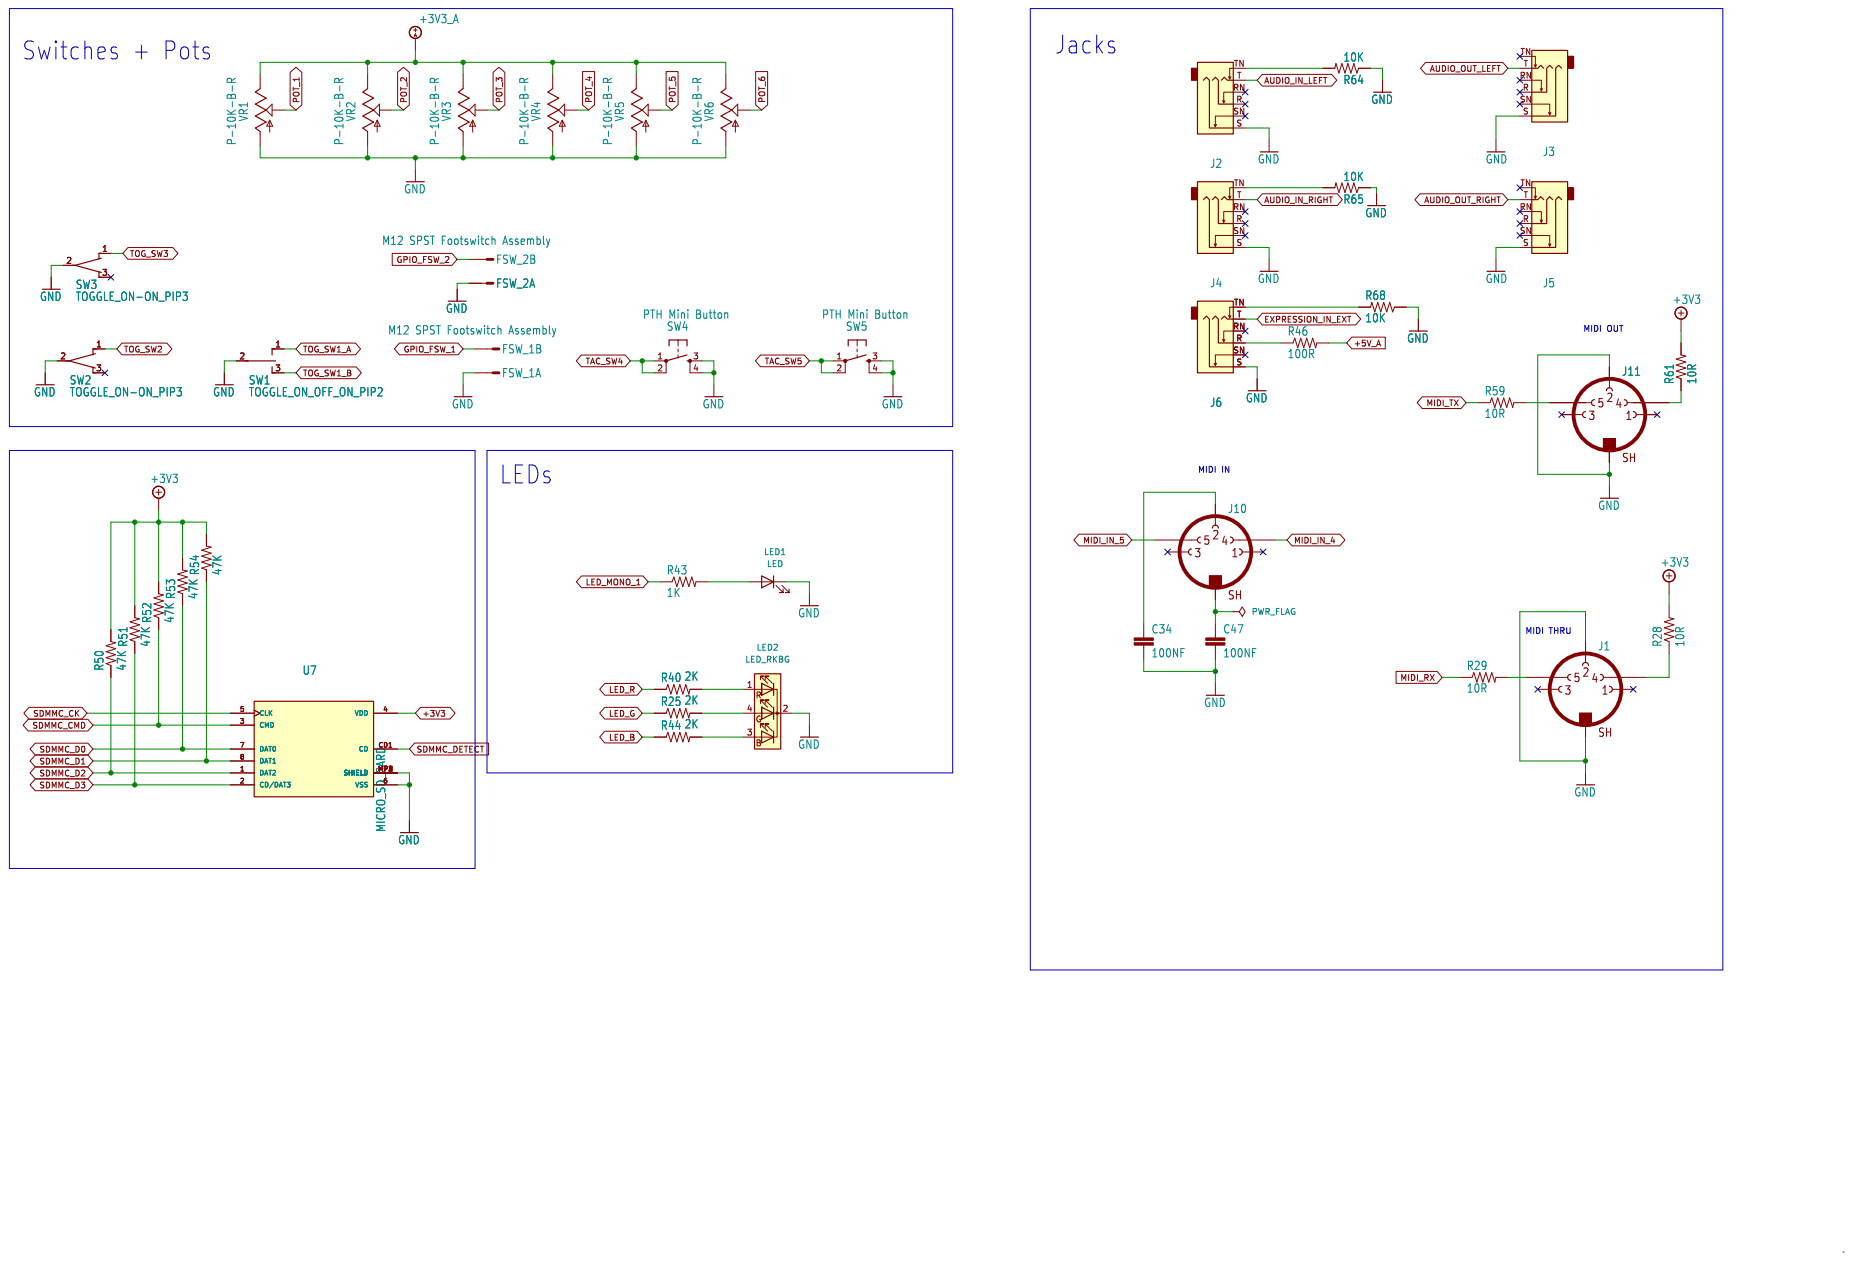
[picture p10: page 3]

MIDI THRU MIDI OUT SD Card

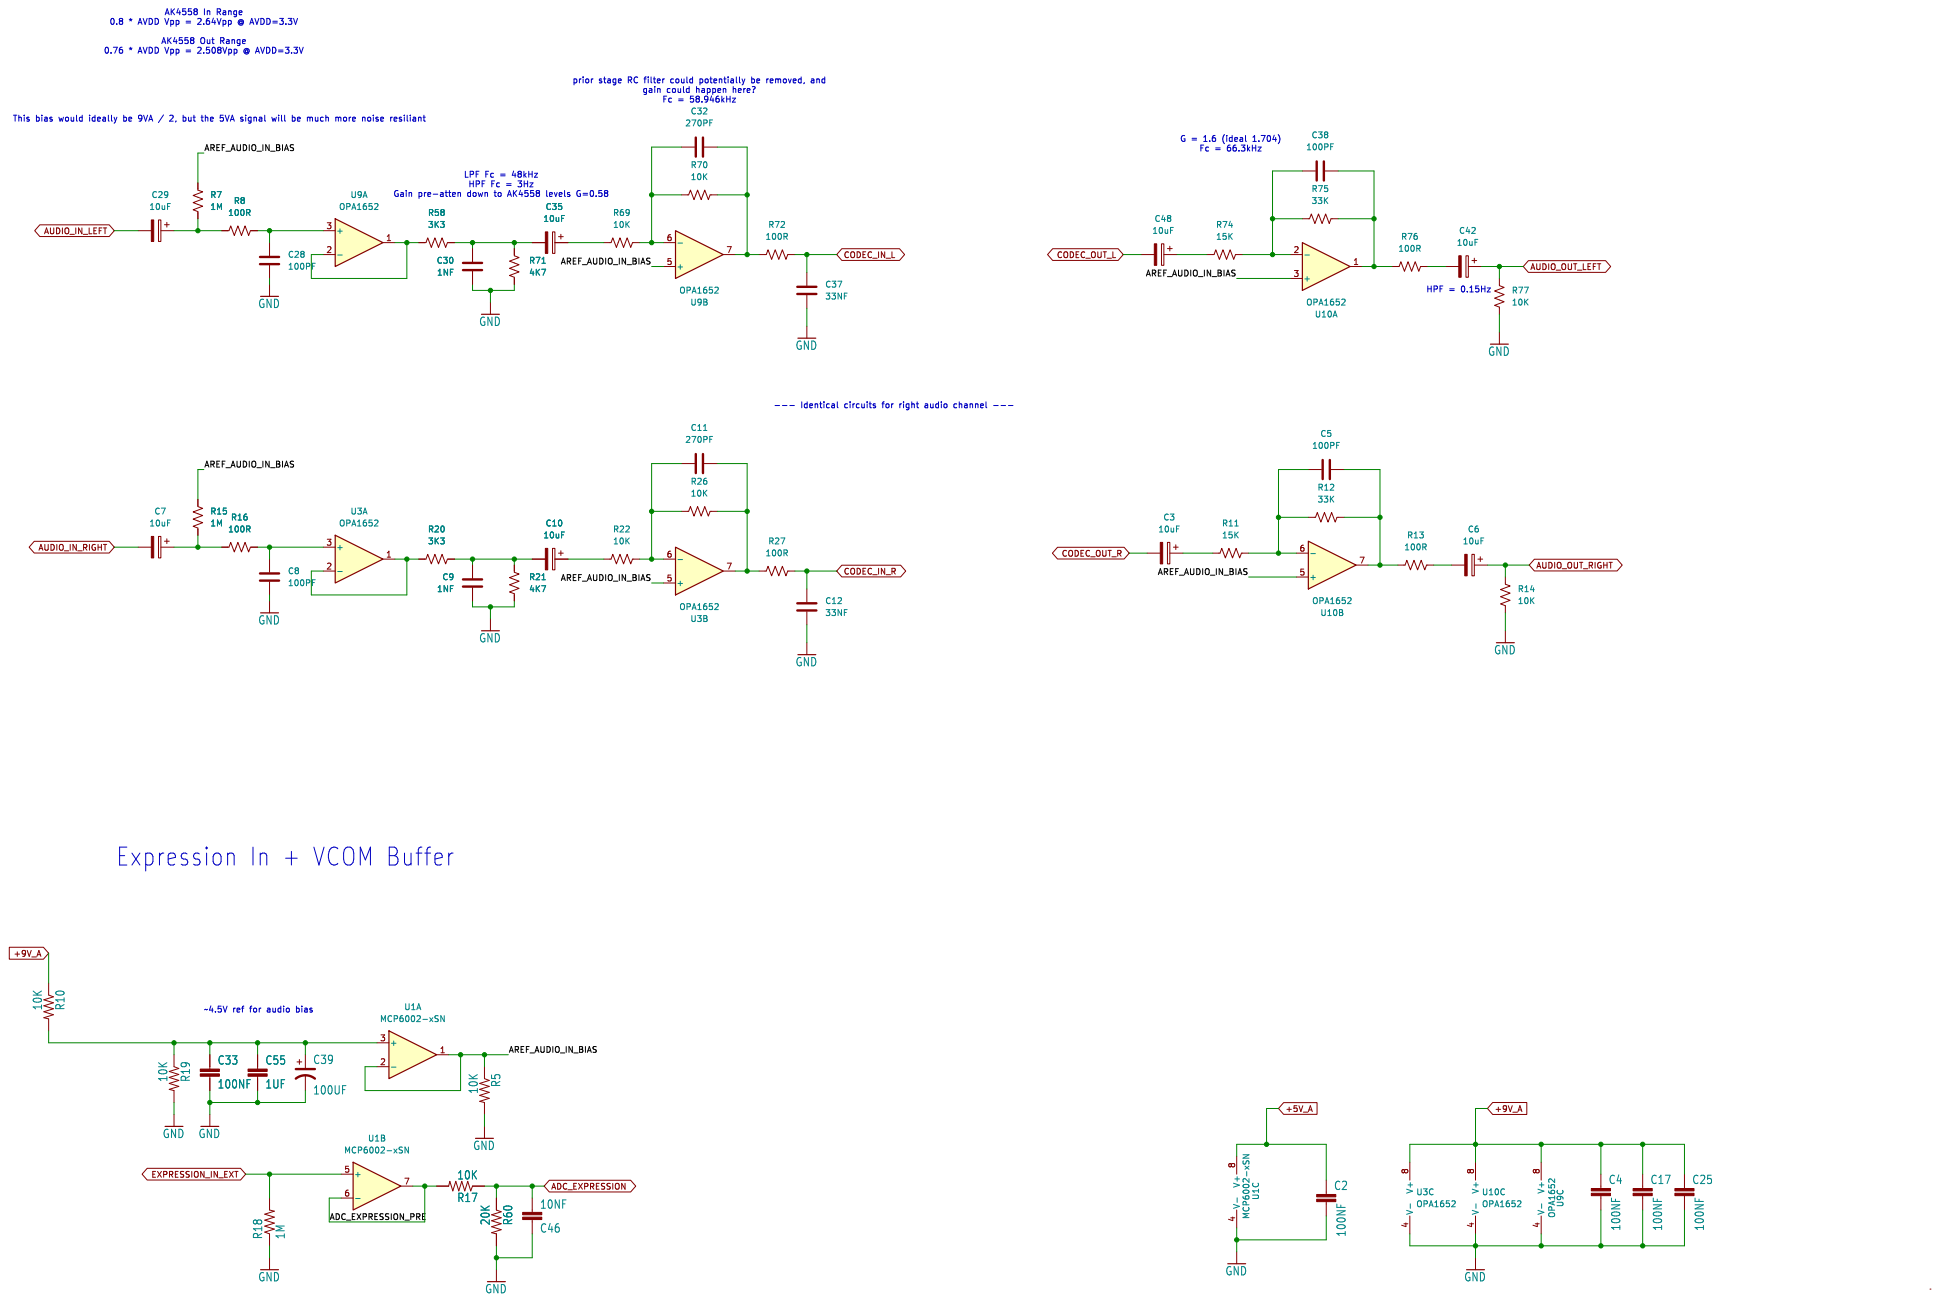
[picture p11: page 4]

gain could happen here? Fc = 58.946kHz

~4.5V ref for audio bias

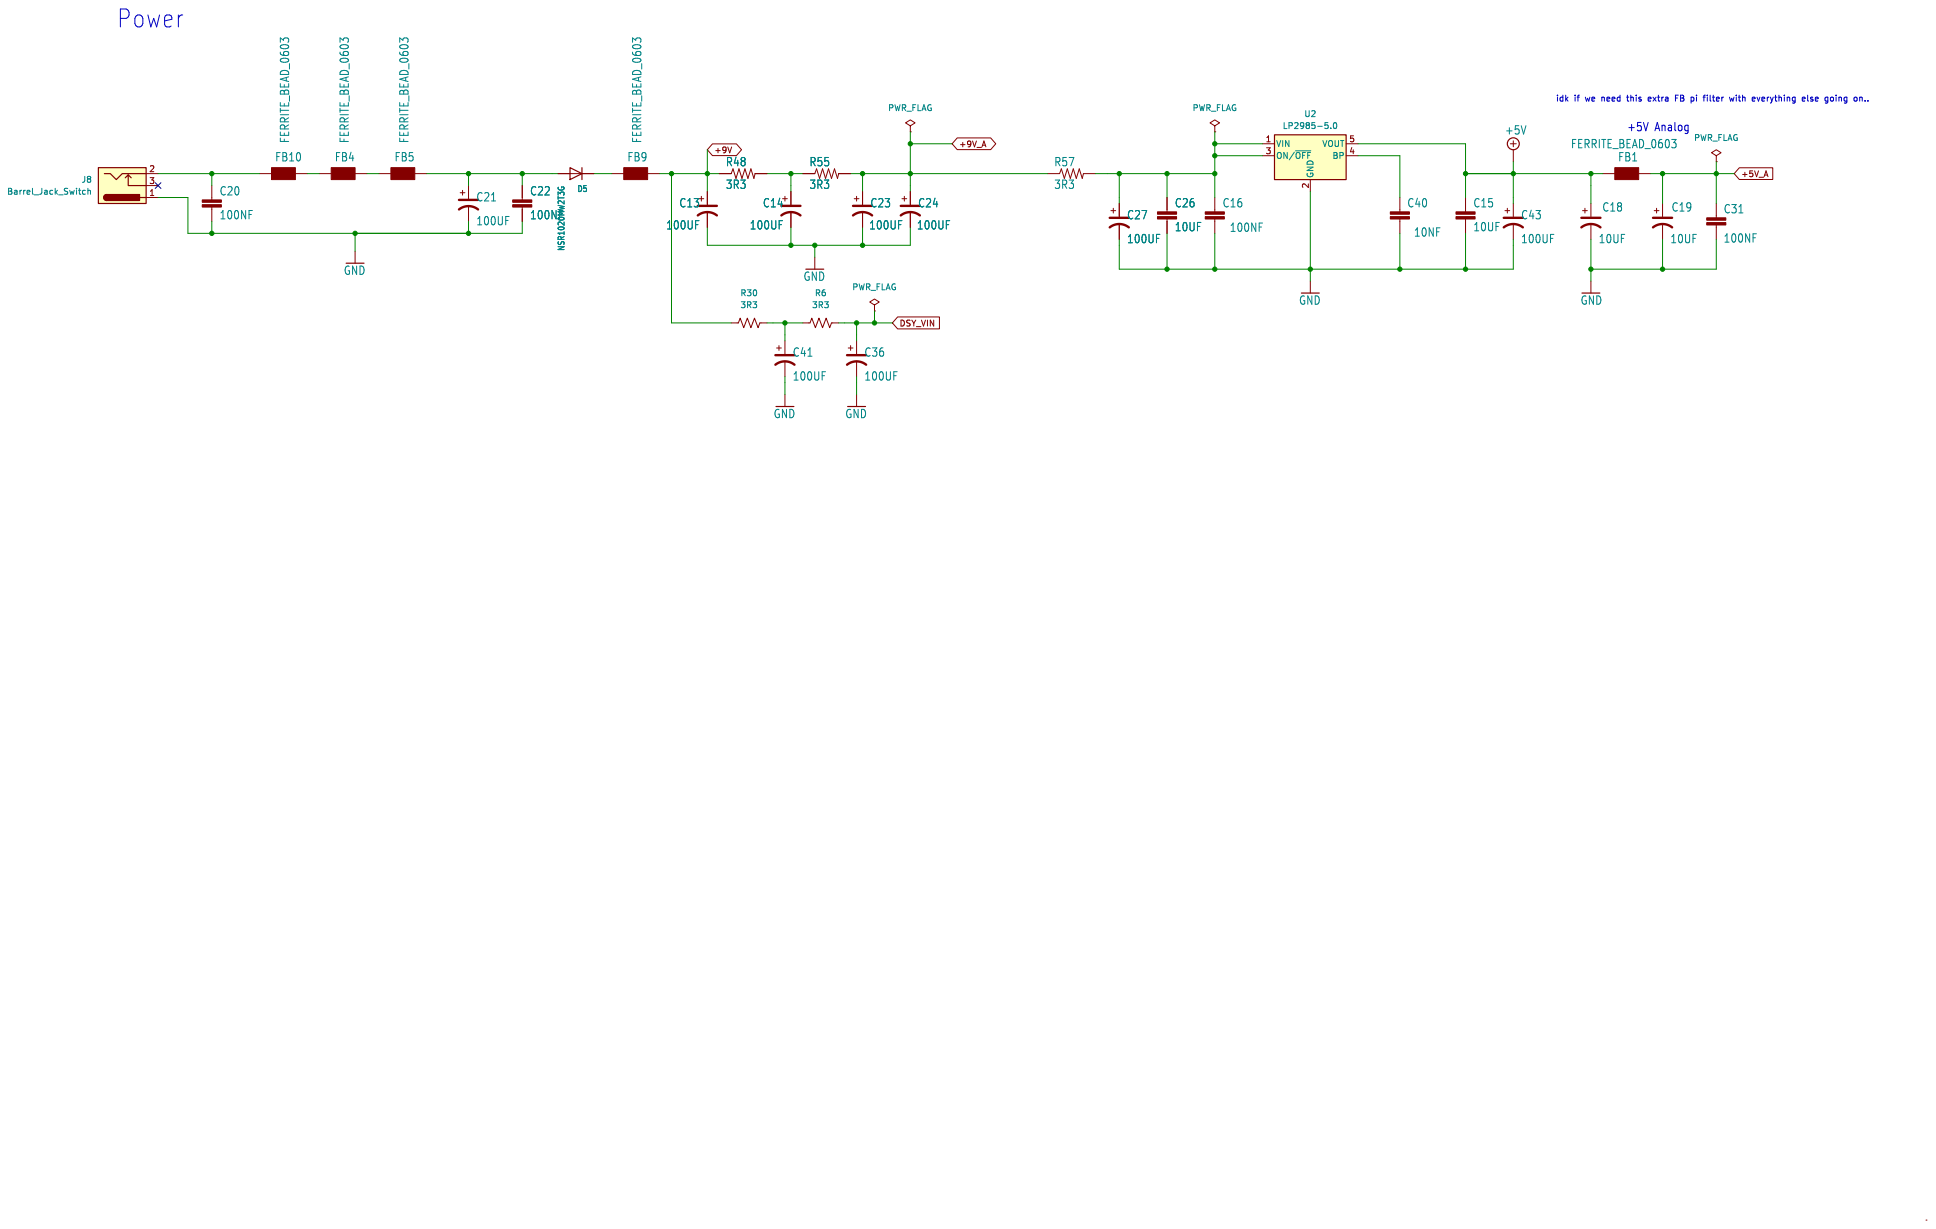
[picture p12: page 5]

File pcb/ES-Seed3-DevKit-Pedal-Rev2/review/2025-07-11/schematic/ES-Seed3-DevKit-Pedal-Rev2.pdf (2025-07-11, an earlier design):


File: ES-Seed3-DevKit-Pedal-Rev1_3.kicad_sch Daisy File: ES-Seed3-DevKit-Pedal-Rev1_1.kicad_sch

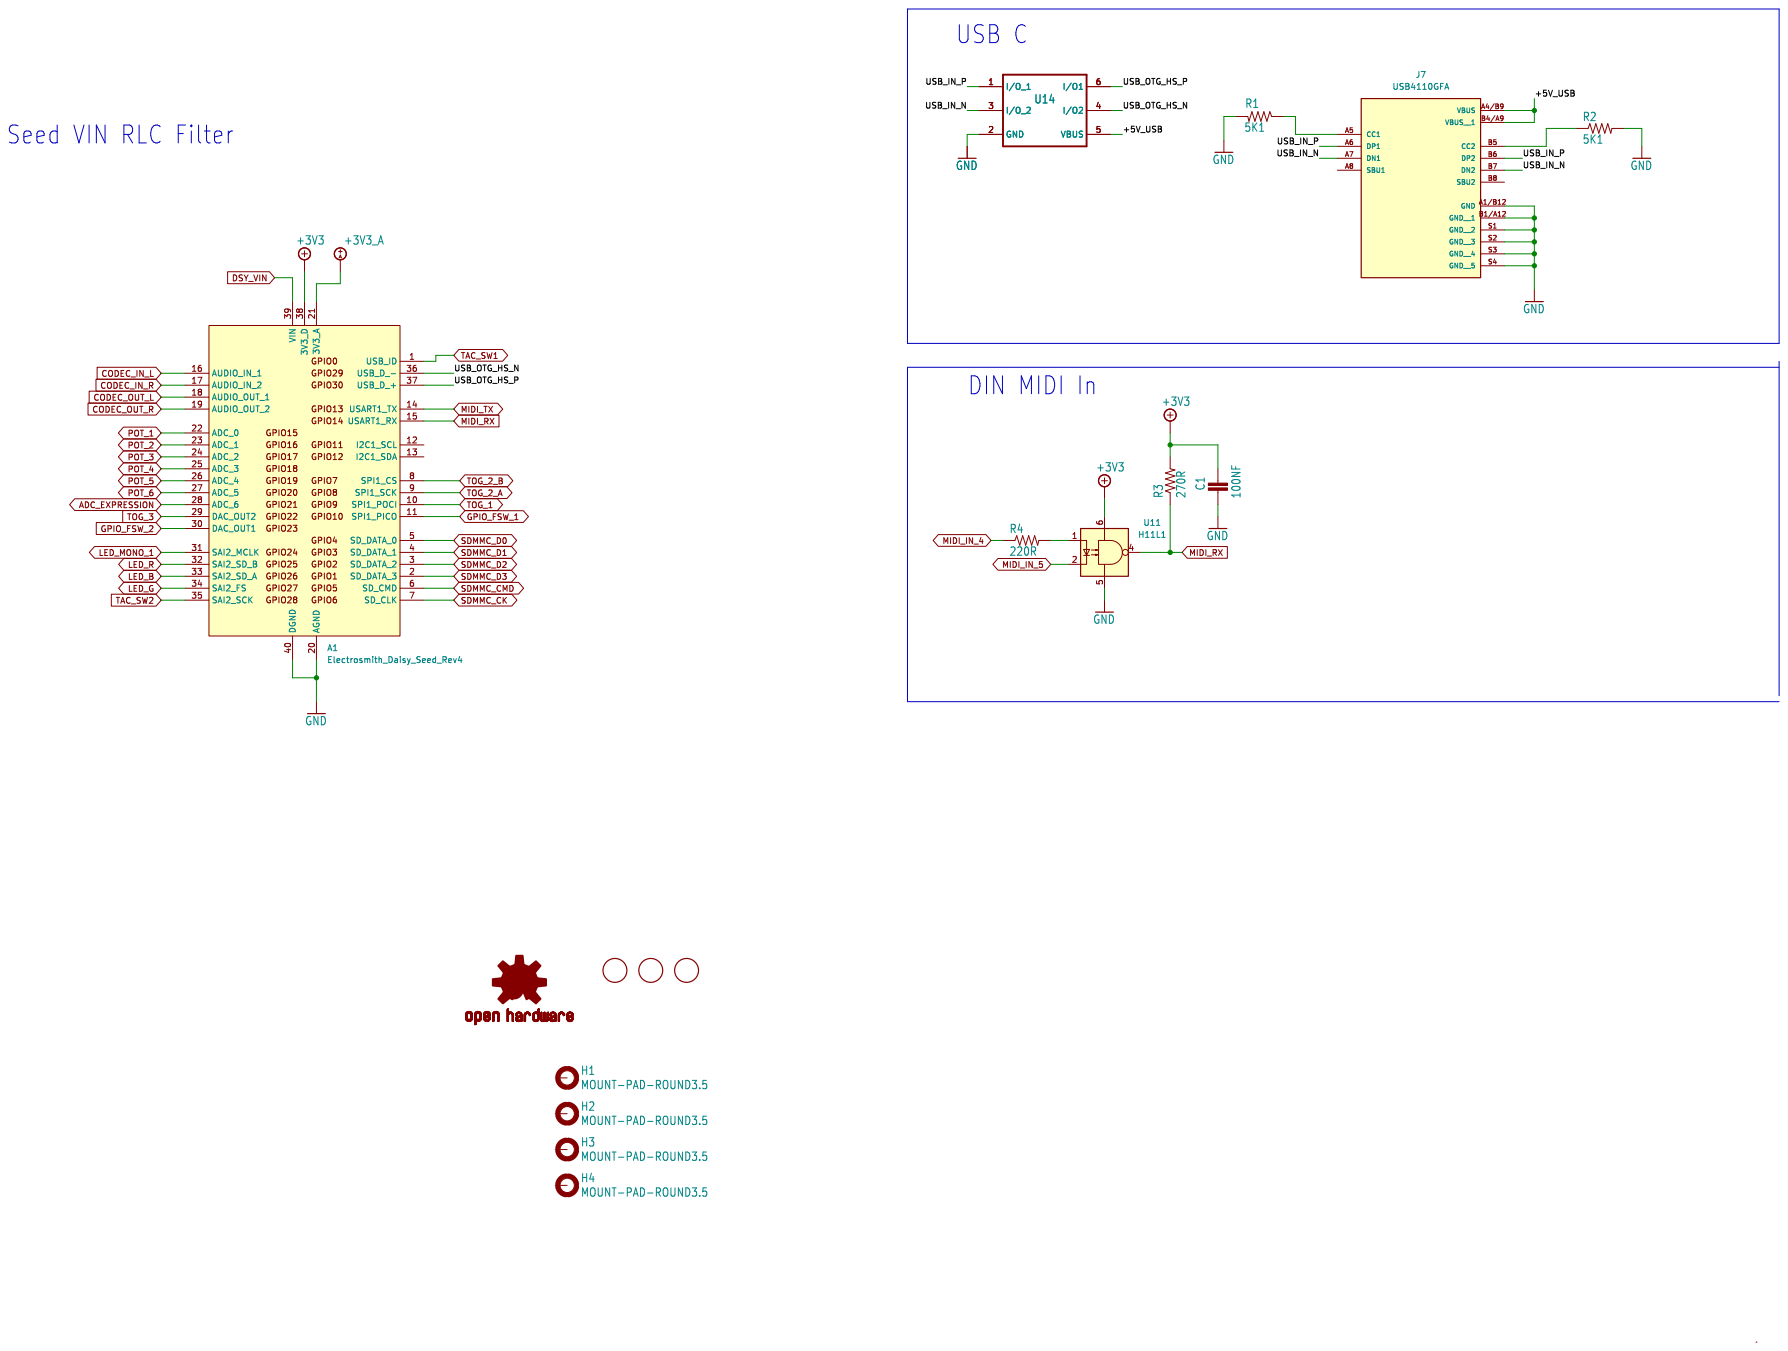
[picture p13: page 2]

Seed VIN RLC Filter

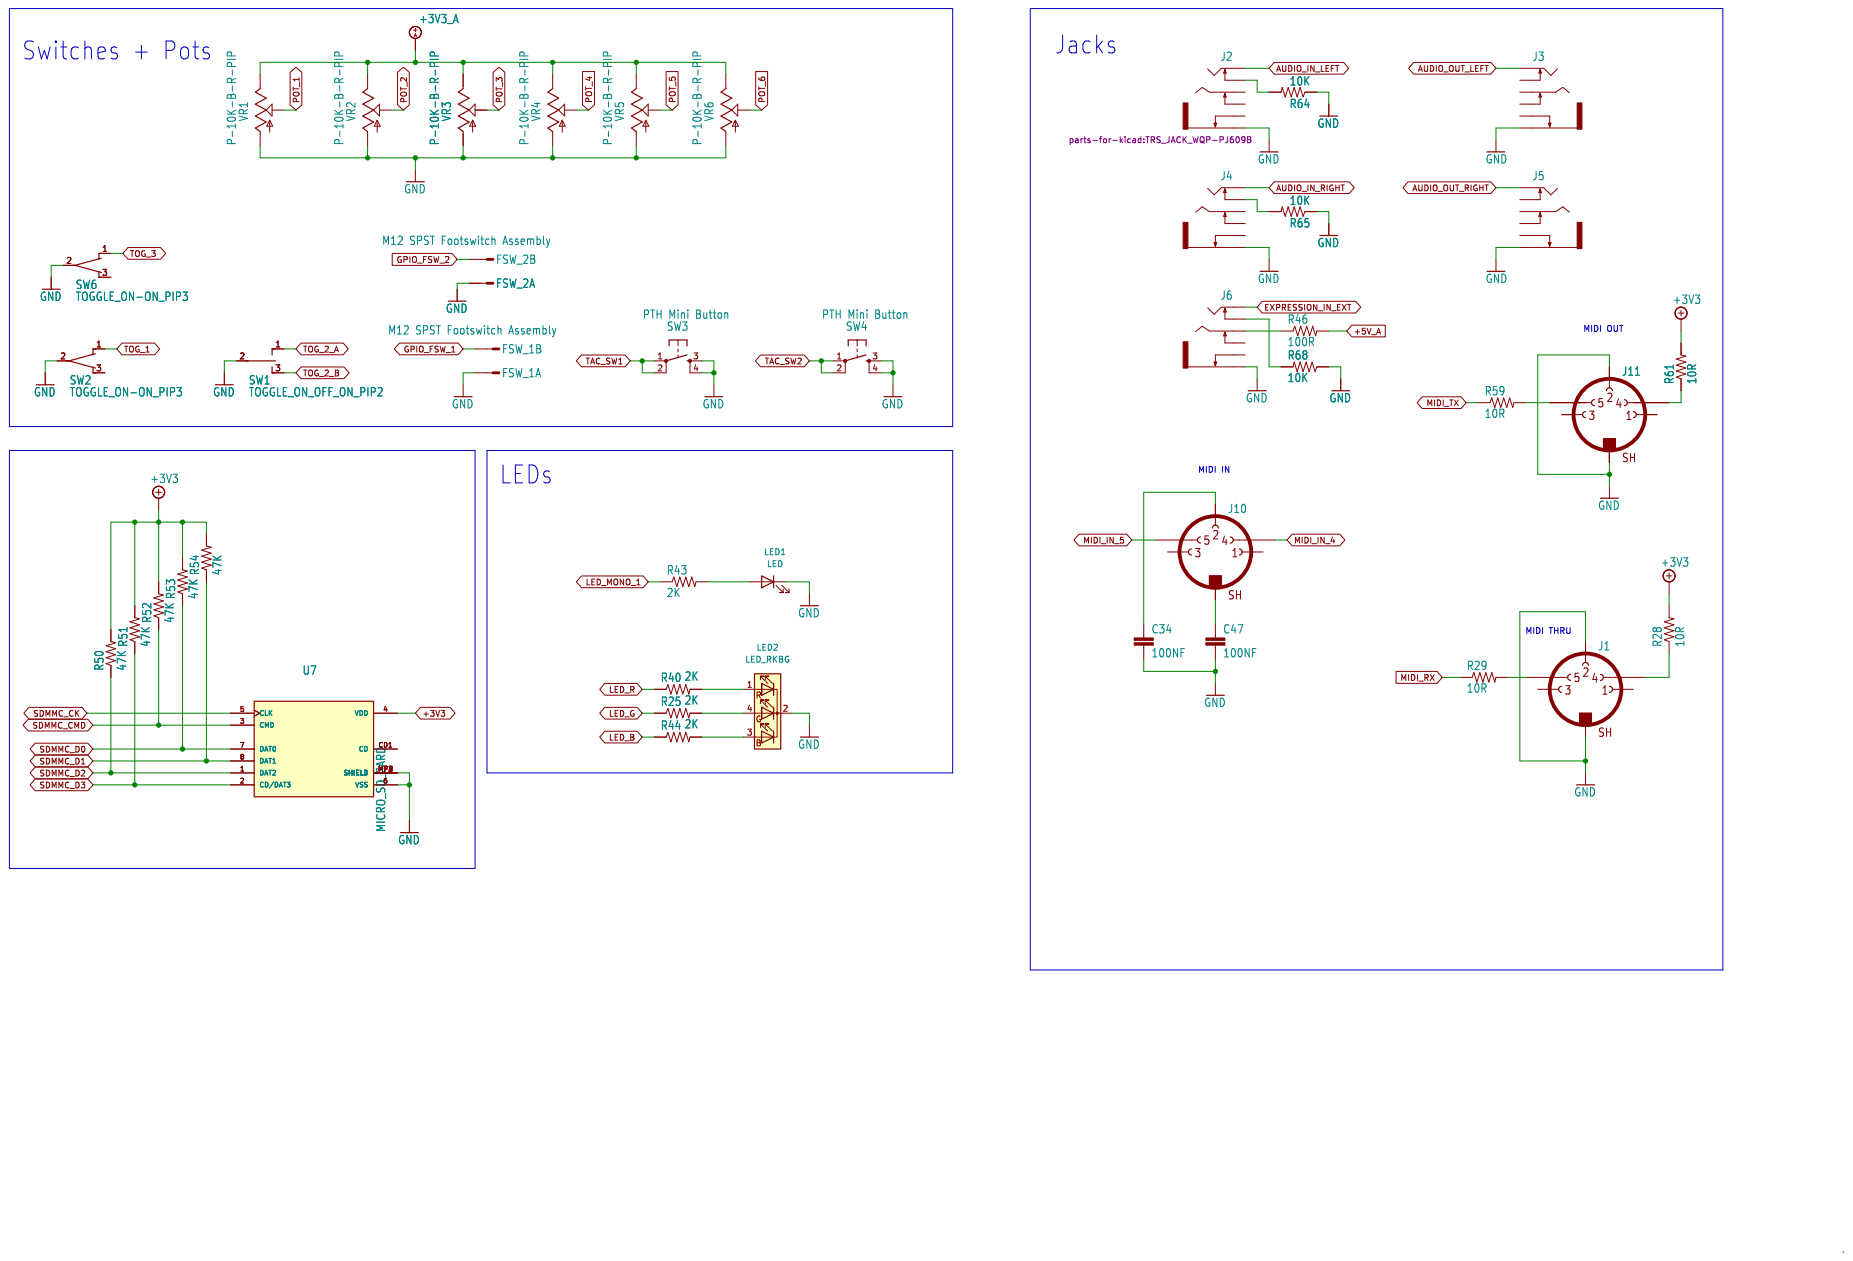
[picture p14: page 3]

MIDI THRU MIDI IN Switches + Pots


Fc = 1.5MHz This can be tested for removal Expression In + VCOM Buffer
7 U3B OPA1652 R17

1.67V ref for audio bias









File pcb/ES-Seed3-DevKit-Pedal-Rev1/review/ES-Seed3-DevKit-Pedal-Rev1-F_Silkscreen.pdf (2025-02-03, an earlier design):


EXPRESSION IN MIDI OUT

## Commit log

2025-01-09 added kicad files, and readme.
    [ES_Daisy_Seed2_DFM_EVAL_PEDAL_Rev5_1.kicad_sch, ES_Daisy_Seed2_DFM_EVAL_PEDAL_Rev5_2.kicad_sch, ES_Daisy_Seed2_DFM_EVAL_PEDAL_Rev5_3.kicad_sch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]
2025-01-22 everything's on the board.
    [ES_Daisy_Seed2_DFM_EVAL_PEDAL_Rev5_1.kicad_sch, ES_Daisy_Seed2_DFM_EVAL_PEDAL_Rev5_2.kicad_sch, ES_Daisy_Seed2_DFM_EVAL_PEDAL_Rev5_3.kicad_sch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]
2025-01-22 fully routed.
    [ES_Daisy_Seed2_DFM_EVAL_PEDAL_Rev5_1.kicad_sch, ES_Daisy_Seed2_DFM_EVAL_PEDAL_Rev5_2.kicad_sch, Seed3-Pedal-DevKit-Converted.kicad_pcb]
2025-01-23 first round of gerbs.
    [ES_Daisy_Seed2_DFM_EVAL_PEDAL_Rev5_2.kicad_sch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]
2025-01-23 first pass on bom, and a quick re-export with better board info.
    [Seed3-Pedal-DevKit-Converted-B_Cu.gbr, Seed3-Pedal-DevKit-Converted-B_Mask.gbr, Seed3-Pedal-DevKit-Converted-B_Paste.gbr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]
2025-01-24 everything except for rounding corners and renaming
    [Seed3-Pedal-DevKit-Converted.kicad_pcb]
2025-01-24 renamed project and remade gerbers.
    [ES-Seed3-DevKit-Pedal-Rev1-B_Cu.gbr, ES-Seed3-DevKit-Pedal-Rev1-B_Mask.gbr, ES-Seed3-DevKit-Pedal-Rev1-B_Paste.gbr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]
2025-01-24 smt buttons pth again, and about to swap sd card.
    [ES-Seed3-DevKit-Pedal-Rev1.kicad_pcb, ES-Seed3-DevKit-Pedal-Rev1_2.kicad_sch]
2025-01-24 new sdcard , lot of routing changes, and new gerbers
    [ES-Seed3-DevKit-Pedal-Rev1-B_Cu.gbr, ES-Seed3-DevKit-Pedal-Rev1-B_Mask.gbr, ES-Seed3-DevKit-Pedal-Rev1-B_Paste.gbr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]
2025-01-24 updated gerbs with matte material for mask.
    [ES-Seed3-DevKit-Pedal-Rev1-B_Cu.gbr, ES-Seed3-DevKit-Pedal-Rev1-B_Mask.gbr, ES-Seed3-DevKit-Pedal-Rev1-B_Paste.gbr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]
2025-01-24 Created production folder and added bom and gerbers zip
    [ES-Seed3-DevKit-Pedal-Rev1-B_Cu.gbr, ES-Seed3-DevKit-Pedal-Rev1-B_Mask.gbr, ES-Seed3-DevKit-Pedal-Rev1-B_Paste.gbr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]
2025-01-24 updated prod mats
    [ES-Seed3-Pedal-DevKit-Rev1-BOM.xlsx, ES-Seed3-Pedal-DevKit-Rev1-CENTROID.csv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]
2025-01-24 new centroid.
    [ES-Seed3-DevKit-Pedal-Rev1-top-pos.csv]
2025-01-24 cleaned up prod mats folder
    [ES-Seed3-Pedal-DevKit-Rev1-BOM.xlsx, ES-Seed3-Pedal-DevKit-Rev1-CENTROID.csv]
2025-02-03 new gerbers, new centroid, new review pdfs
    [ES-Seed3-DevKit-Pedal-Rev1-B_Cu.gbr, ES-Seed3-DevKit-Pedal-Rev1-B_Mask.gbr, ES-Seed3-DevKit-Pedal-Rev1-B_Paste.gbr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]
2025-02-03 fixed headers in pos csv.
    [ES-Seed3-DevKit-Pedal-Rev1-top-pos.csv]
2025-02-03 added new gerbs and centroid to production folder
    [ES-Seed3-DevKit-Pedal-Rev1-B_Cu.gbr, ES-Seed3-DevKit-Pedal-Rev1-B_Mask.gbr, ES-Seed3-DevKit-Pedal-Rev1-B_Paste.gbr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]
2025-02-03 removed paste layers from gerber zip
    [ES-Seed3-DevKit-Pedal-Rev1-B_Paste.gbr, ES-Seed3-DevKit-Pedal-Rev1-F_Paste.gbr, ES-Seed3-DevKit-Pedal-Rev1-job.gbrjob]
2025-02-03 tweaked centroid to match jlc pref
    [ES-Seed3-Pedal-DevKit-Rev1-CENTROID.csv]
2025-02-03 tweaked back to actual jlc pref on centroid
    [ES-Seed3-Pedal-DevKit-Rev1-CENTROID.csv]
2025-07-08 starting rev2 file in a new project.
    [ES-Seed3-DevKit-Pedal-Rev1_1.kicad_sch, ES-Seed3-DevKit-Pedal-Rev1_2.kicad_sch, ES-Seed3-DevKit-Pedal-Rev1_3.kicad_sch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]
2025-07-08 removed true bypass/relays from sch
    [ES-Seed3-DevKit-Pedal-Rev1_1.kicad_sch, ES-Seed3-DevKit-Pedal-Rev1_3.kicad_sch, ES-Seed3-DevKit-Pedal-Rev2.kicad_sch]
2025-07-09 I think schematic is done, board is updated -- needs layout and final routing.
    [ES-Seed3-DevKit-Pedal-Rev1_3.kicad_sch, ES-Seed3-DevKit-Pedal-Rev2.kicad_pcb]
2025-07-10 board is done -- working on prod mat generation, and then reviewing
    [ES-Seed3-DevKit-Pedal-Rev2-B_Cu.gbl, ES-Seed3-DevKit-Pedal-Rev2-B_Fab.gbr, ES-Seed3-DevKit-Pedal-Rev2-B_Mask.gbs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]
2025-07-10 updated production generation to include THT in centroid, and to properly name the gerbers zip.
    [ES-Seed3-DevKit-Pedal-Rev1_1.kicad_sch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]
2025-07-11 updated prod before review.
    [ES-Seed3-DevKit-Pedal-Rev2-B_Cu.gbl, ES-Seed3-DevKit-Pedal-Rev2-B_Fab.gbr, ES-Seed3-DevKit-Pedal-Rev2-B_Mask.gbs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]
2025-07-11 updated board with requested changes, and remade prod.
    [ES-Seed3-DevKit-Pedal-Rev2-B_Cu.gbl, ES-Seed3-DevKit-Pedal-Rev2-B_Fab.gbr, ES-Seed3-DevKit-Pedal-Rev2-B_Mask.gbs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]
2025-07-11 updated gerbers with fixed silk screen>
    [ES-Seed3-DevKit-Pedal-Rev2-B_Cu.gbl, ES-Seed3-DevKit-Pedal-Rev2-B_Fab.gbr, ES-Seed3-DevKit-Pedal-Rev2-B_Mask.gbs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]
2025-07-11 more silk fixes, and removed paste from toggles
    [ES-Seed3-DevKit-Pedal-Rev2-B_Cu.gbl, ES-Seed3-DevKit-Pedal-Rev2-B_Fab.gbr, ES-Seed3-DevKit-Pedal-Rev2-B_Mask.gbs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]
2025-11-17 rev3 from rev2, with most of the changes made (also random view/column settings in rev1 project?
    [ES-Seed3-DevKit-Pedal-Rev1_1.kicad_sch, ES-Seed3-DevKit-Pedal-Rev1_2.kicad_sch, ES-Seed3-DevKit-Pedal-Rev1_3.kicad_sch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]
2025-11-18 first review/prod folders after making all changes.
    [ES-Seed3-DevKit-Pedal-Rev1_1.kicad_sch, ES-Seed3-DevKit-Pedal-Rev1_2.kicad_sch, ES-Seed3-DevKit-Pedal-Rev1_4.kicad_sch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]
2025-11-18 new prod/review for first pass of review, along with README for PCB changes.
    [ES-Seed3-DevKit-Pedal-Rev3-B_Cu.gbl, ES-Seed3-DevKit-Pedal-Rev3-B_Fab.gbr, ES-Seed3-DevKit-Pedal-Rev3-B_Mask.gbs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]
2025-12-08 boxes around daisy pins, osh logo fix, etc.
    [ES-Seed3-DevKit-Pedal-Rev1_1.kicad_sch, ES-Seed3-DevKit-Pedal-Rev3.kicad_pcb]
2025-12-08 prod mats with last bits of silk adjustment.
    [ES-Seed3-DevKit-Pedal-Rev1_1.kicad_sch, ES-Seed3-DevKit-Pedal-Rev1_2.kicad_sch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]
2025-12-08 moved silk for the gates.
    [ES-Seed3-DevKit-Pedal-Rev3-B_Cu.gbl, ES-Seed3-DevKit-Pedal-Rev3-B_Fab.gbr, ES-Seed3-DevKit-Pedal-Rev3-B_Mask.gbs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]
2025-12-10 post-review regen
    [ES-Seed3-DevKit-Pedal-Rev3-B_Cu.gbl, ES-Seed3-DevKit-Pedal-Rev3-B_Fab.gbr, ES-Seed3-DevKit-Pedal-Rev3-B_Mask.gbs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]
2025-12-10 fixed QR code to be correct destination link, and removed DNIs.
    [ES-Seed3-DevKit-Pedal-Rev1_1.kicad_sch, ES-Seed3-DevKit-Pedal-Rev1_3.kicad_sch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]
2026-06-25 Rev4 - added missing diode, regenerated review/production mats (#17)
    * opened project in kicad10
    * Rev4 - Added diode to MIDI input, regenerated prod, etc.
    * fixed planes, updated bom job, and regen prod mats.
    * updated prod w/ BOM including qty for OBSY upload.
    [ES-Seed3-DevKit-Pedal-Rev1_1.kicad_sch, ES-Seed3-DevKit-Pedal-Rev1_2.kicad_sch, ES-Seed3-DevKit-Pedal-Rev1_3.kicad_sch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]
2026-10-06 New readme (#18)
    * Enhance README with detailed information
    Expanded the README to include detailed features, specifications, and getting started instructions for the Seed3 Pedal Dev Kit.
    * Replace pinout image with new asset URL
    Updated pinout image in README with a new asset URL.
    * Update image tag for hardware reference section
    * Revise specifications in README.md
    Updated specifications for audio codec, input impedance, and board dimensions in README.
    * Revise README with updated license and trademark info
    Updated licensing information and trademark details for the Pedal Dev Kit in the README.
    * Update Dev Kit name to 'Pedal Dev Kit' in README
    * Add files via upload
    * Revise RE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
2026-11-02 update most parts to built-in kicad libraries, and resolve ERC errors/warnings.
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2026-11-02 oshw logo visibility on board, and ran update (linked by reference) on board, fixed a few reversed resistors.
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2026-11-02 added missing note about rev4 change to pcb/README
2026-11-03 updated USB footprint and DRC settings to resolve errors.
